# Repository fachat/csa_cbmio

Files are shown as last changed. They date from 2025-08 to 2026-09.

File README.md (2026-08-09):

# CBM-IO

Note: this is a part of a larger set of repositories, with [upet_family](https://github.com/fachat/upet_family) as the main repository.

This is the IO board for a re-incarnation of the Commodore B-Series to be used together with the Ultra-CPU board.

It is build on a Eurocard board and has only parts that can still be obtained new in 2025. In fact it uses an FPGA to emulate all the I/O chips of the B-Series.
It uses the [CS/A bus interface](http://www.6502.org/users/andre/csa/index.html) to connect with the CPU board.

Note: this is a work in progress!

The board

## Features

## Contributions

### VIA 6522

The VIA6522 is coming from Rhialto's Mega65 code at https://github.com/Rhialto/MegaPET/blob/rhialto/CORE/PET2001_MiSTer/rtl/via6522.vhd
which in turns originates from Gideon Zweijtzer.

I had to adapt it to the single Phi2 clock input though.

In the meantime it has been mostly rewritten esp. in the timer and shift register parts, along the lines
of the chip dissection from http://forum.6502.org .

### UART 16550

The UART seems to be a common 16550 core, made for the Wishbone bus.
it is taken from the Microwatt project https://github.com/antonblanchard/microwatt
and seems to originate from http://www.opencores.org/cores/uart16550/ but that page is not found anymore.

I again had to adapt it to the 6502 bus interface.

## Thanks

Many thanks go to Frank "androSID" Wolf and Dieter "ttlworks" Müller from the
[6502.org forum](https://forum.6502.org), who dissected the PIA and VIA chips (and many more).
This is an outstanding work and absolutely helpful in understanding how the chips work internally.

The relevant chip dissections are

- [VIA dissection](https://6502.org/forum/viewtopic.php?f=4&t=7241)
- [PIA dissection](https://6502.org/forum/viewtopic.php?f=4&t=7425)

For your interest, the full list of chip dissection is here [here on the forum](https://6502.org/forum/viewtopic.php?t=7427)

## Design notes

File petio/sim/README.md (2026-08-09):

# PETIO IC simulation scripts (GHDL)

This folder provides cycle-driven GHDL testbenches for:

- `via6522`
- `pia6520`
- `uart_shell`
- `Shell` (with a cycle-exact 6502 CPU model)

## Script format

Each line defines one cycle action (used by the via/pia/uart testbenches):

```text
<cycle> <op> [addr] [data]
```

- `cycle`: non-negative integer, strictly increasing
- `op`:
  - `W` write register (`addr` + `data` required)
  - `R` read register (`addr` required)
  - `N` no bus operation (pause)
- `addr`: register index in decimal
- `data`: byte value (0..255) in decimal

Blank lines and lines starting with `#` are ignored.

Pauses can be modeled in two ways:
- by using explicit `N` lines
- by leaving gaps between cycle numbers

## Run

From `/home/runner/work/csa_cbmio/csa_cbmio/petio/sim`:

- `make via`
- `make pia`
- `make uart`
- `make shell_cpu ROM=path/to/rom.bin`

Override script file:

- `make via SCRIPT=scripts/my_via.txt`

## Shell CPU testbench (`tb_shell_cpu`)

`tb_shell_cpu.vhd` instantiates the full `Shell.vhd` design and drives it with
the extracted `cpu6502.vhd` cycle-accurate behavioural 6502 CPU model.

### Memory map

| Address range | Description |
|---|---|
| `$0000–$03FF` | 1 kB RAM |
| `$E800–$E87F` | Shell I/O (`niosel` asserted) |
| `$E000–$FFFF` | 8 kB ROM loaded from `rom_file` (except `$E800–$E87F`, where Shell I/O has priority) |

### ROM loading

The ROM binary is specified via the `rom_file` generic (default: `rom.bin`).
If the binary is smaller than 8 kB it is placed at the **end** of the ROM
region so that the 6502 vector area (`$FFFA–$FFFF`) is always populated.

### Simulation flow

1. `nres` is held low for 8 clock cycles (reset).
2. `nres` is released; the CPU fetches the reset vector from `$FFFC/$FFFD`
   and begins executing ROM code.
3. Simulation ends when the CPU executes a `BRK` instruction (`$00`) or
   after 1 000 000 bus cycles (safety timeout).

### Running

```sh
make shell_cpu ROM=mytest.bin
```

The waveform is written to `shell_cpu.vcd`.

### Test fixture — exposed pin connections

To allow ROM test programs to exercise the I/O ports end-to-end, the
testbench cross-wires certain exposed pins so that writing to one pin and
reading back the opposite pin of the pair exercises the full output→wire→input
path. `std_logic` resolution is used throughout: whichever endpoint is
configured as an output drives the shared node with `'0'` or `'1'`; the
opposite end (configured as an input) drives the node with `'Z'`, which the
resolver ignores.

| Connection | Shell signal A | Shell signal B | Notes |
|---|---|---|---|
| VIA1 PA0 ↔ VIA1 PA1 | `up(0)` | `up(1)` | bidirectional |
| VIA1 PA2 ↔ VIA1 PA3 | `up(2)` | `up(3)` | bidirectional |
| VIA1 PA4 ↔ VIA1 PB3 | `up(7)` | `cwr` | bidirectional |
| VIA1 PA5 ↔ VIA1 PA6 | `up(6)` | `up(5)` | bidirectional |
| PIA1 PA7 ↔ VIA1 CB1 | `up(10)` | `up(12)` | bidirectional |
| PIA1 CA1 ↔ VIA1 CA2 | `c1rd` | `up(11)` | VIA1 CA2 → PIA1 CA1 only; PIA CA1 is always an input; `'1'` (idle) when CA2 is in input mode |

The pin mapping within `Shell.vhd` that translates internal VIA/PIA signals
to the Shell's external ports:

| VIA1/PIA1 pin | Shell external port bit |
|---|---|
| VIA1 PA0 | `up(0)` |
| VIA1 PA1 | `up(1)` |
| VIA1 PA2 | `up(2)` |
| VIA1 PA3 | `up(3)` |
| VIA1 PA4 | `up(7)` |
| VIA1 PA5 | `up(6)` |
| VIA1 PA6 | `up(5)` |
| VIA1 PB3 | `cwr` |
| VIA1 CA2 | `up(11)` |
| VIA1 CB1 | `up(12)` |
| PIA1 PA7 | `up(10)` |
| PIA1 CA1 | `c1rd` |

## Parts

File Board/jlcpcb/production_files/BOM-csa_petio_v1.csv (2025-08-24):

Comment | Designator | Footprint | LCSC | Quantity
4k7 | RN6 | R_Array_SIP5 | C11392 | 1
74LVC1G125 | U21,U22 | SOT-353_SC-70-5 | C12519 | 2
47u | C8 | C_0805_2012Metric_Pad1.18x1.45mm_HandSolder | C16780 | 1
Extended_PET_keyboard_connector | J14 | PET_Extended_Keyboard_Connector | C18202145 | 1
M09HPS | X3 | DSUB-9_Pins_Horizontal_P2.77x2.84mm_EdgePinOffset9.90mm_Housed_MountingHolesOffset11.32mm | C19077344 | 1
1k | R10,R3,R9 | R_0603_1608Metric_Pad0.98x0.95mm_HandSolder | C21190 | 3
10 | R6 | 0207_10 | C2149605 | 1
74LVC1G04 | U14 | SOT-23-5 | C22356929 | 1
330 | R2,R4,R7,R8 | R_0603_1608Metric_Pad0.98x0.95mm_HandSolder | C23138 | 4
4k7 | R1,R5 | R_0603_1608Metric_Pad0.98x0.95mm_HandSolder | C23162 | 2
SN75161BDW | U5 | SOIC-20W_7.5x12.8mm_P1.27mm | C2671348 | 1
LSF0204Q | U16,U17,U18,U19,U6,U7,U8,U9 | TSSOP-14_4.4x5mm_P0.65mm | C2677502 | 8
XC6SLX9-TQG144 | U1 | TQFP-144_20x20mm_P0.5mm | C27408 | 1
74LVC8T245SO24 | IC16 | TSSOP-24_6.1x7.8mm_P0.65mm | C27643 | 1
100n | C1,C10,C15,C16,C17,C18,C19,C2,C20,C21,C22,C23,C24,C25,C26,C27,C28,C29,C3,C30,C31,C32,C33,C34,C35,C36,C37,C38,C39,C40,C9 | C_0805_2012Metric | C28233 | 31
1u | C11,C12,C13,C14 | C_0805_2012Metric_Pad1.18x1.45mm_HandSolder | C28323 | 4
AP2132BB | UX16 | Diodes_PSOP-8 | C338874 | 1
22u | C4,C5,C6,C7 | C_0805_2012Metric_Pad1.18x1.45mm_HandSolder | C45783 | 4
JP1E | JP1,JP18,JP22 | JP1 | C492401 | 3
CBMTAPE | P5 | JP6 | C492405 | 1
Conn_01x09 | J11,J12 | PinHeader_1x09_P2.54mm_Vertical | C492408 | 2
4051 | U12,U13 | SOP-16_3.9x9.9mm_P1.27mm | C507163 | 2
74LS06 | U10 | SO-14_3.9x8.65mm_P1.27mm | C513512 | 1
PETUSERPORT | P1,P2 | FLAT24_IDC | C5157635 | 2
CSABUS | P4 | CSABUS | C5173362 | 1
~ | P9,UX7 | IDC-Header_2x05_P2.54mm_Vertical | C5665 | 2
LDI1117 | UX17 | SOT-223 | C6186 | 1
ADM560 | U15 | SSOP-28_5.3x10.2mm_P0.65mm | C658278 | 1
SPIFLASH | UX18 | DIP-8_W7.62mm_Socket_LongPads | C72124 | 1
Conn_01x23 | J2 | PinSocket_1x23_P2.54mm_Vertical | C725955 | 1
~ | U20 | IDC-Header_2x13_P2.54mm_Vertical | C7501247 | 1
SN74LVC245APW | U11,U2,U3 | TSSOP-20_4.4x6.5mm_P0.65mm | C7848 | 3
74LVC1G00 | U23 | SOT-353_SC-70-5_Handsoldering | C8185 | 1
10k | RN1,RN2,RN3,RN4,RN5 | R_Array_SIP9 | C8692 | 5
SN75160BDW | U4 | SOIC-20W_7.5x12.8mm_P1.27mm | C882412 | 1
DIN-6 | J1 | DIN6PIEC |  | 1
PIEZOBEEPERPIEZO | BEEP1 | PIEZOBEEPER |  | 1

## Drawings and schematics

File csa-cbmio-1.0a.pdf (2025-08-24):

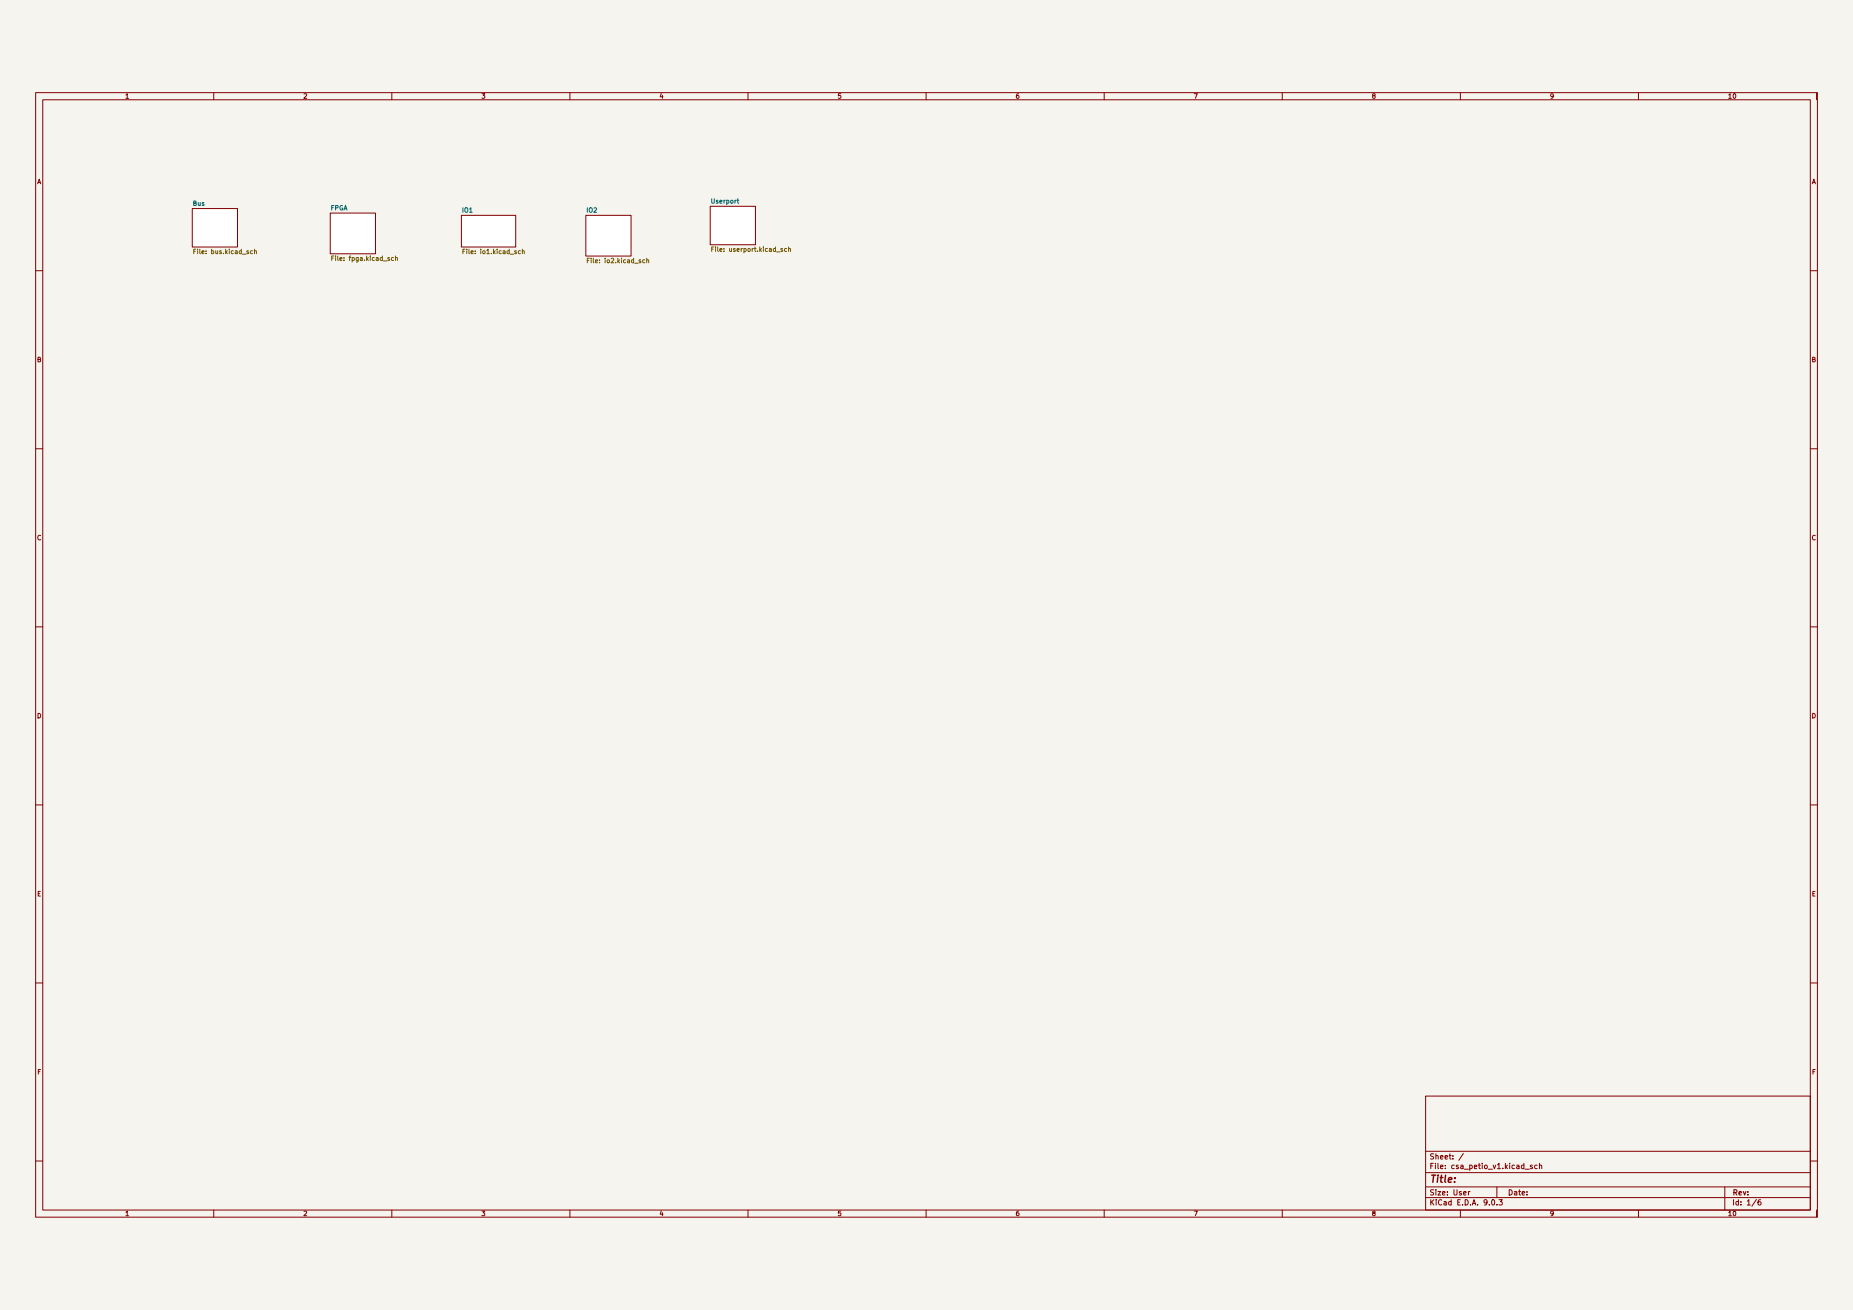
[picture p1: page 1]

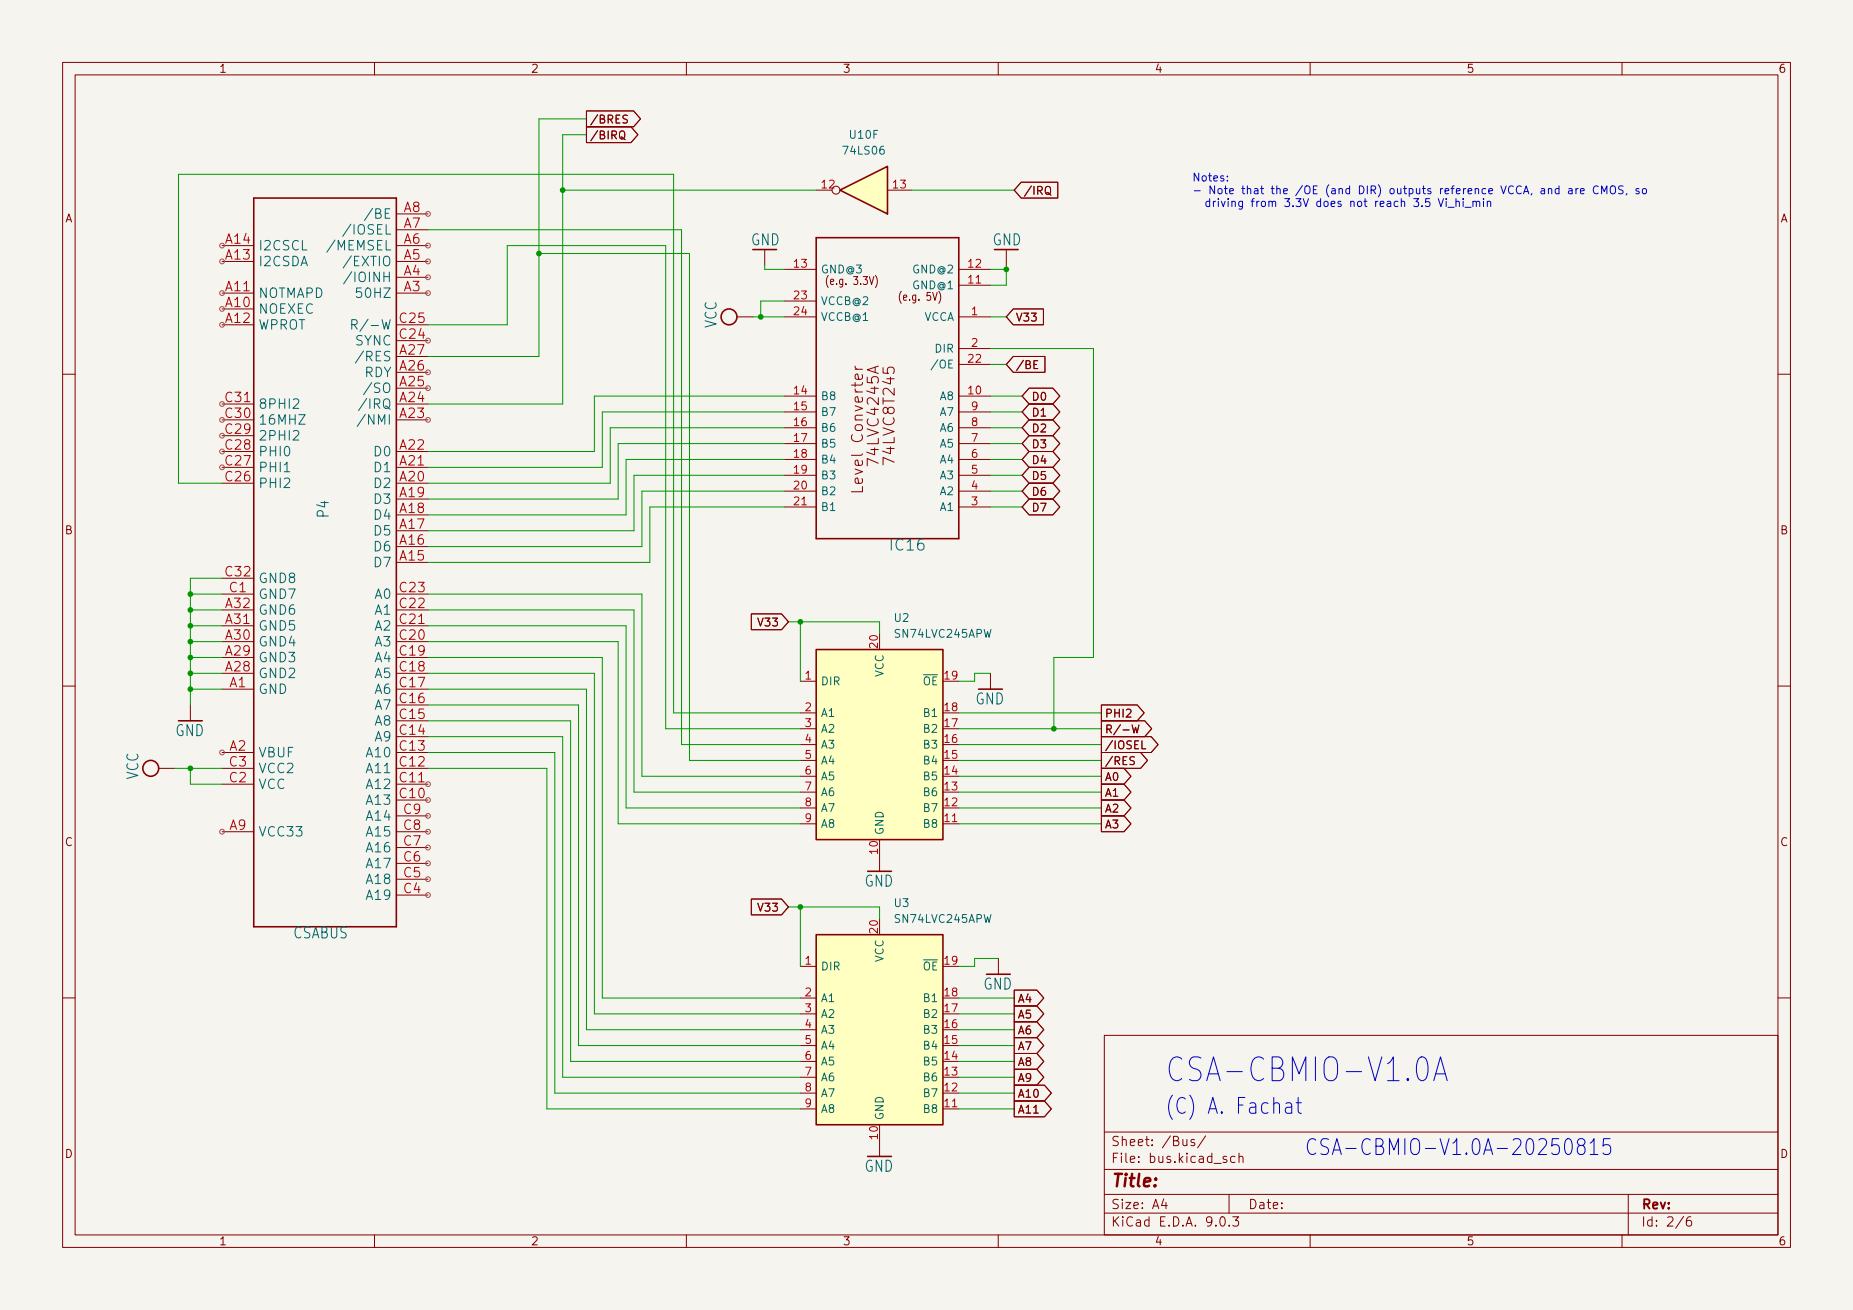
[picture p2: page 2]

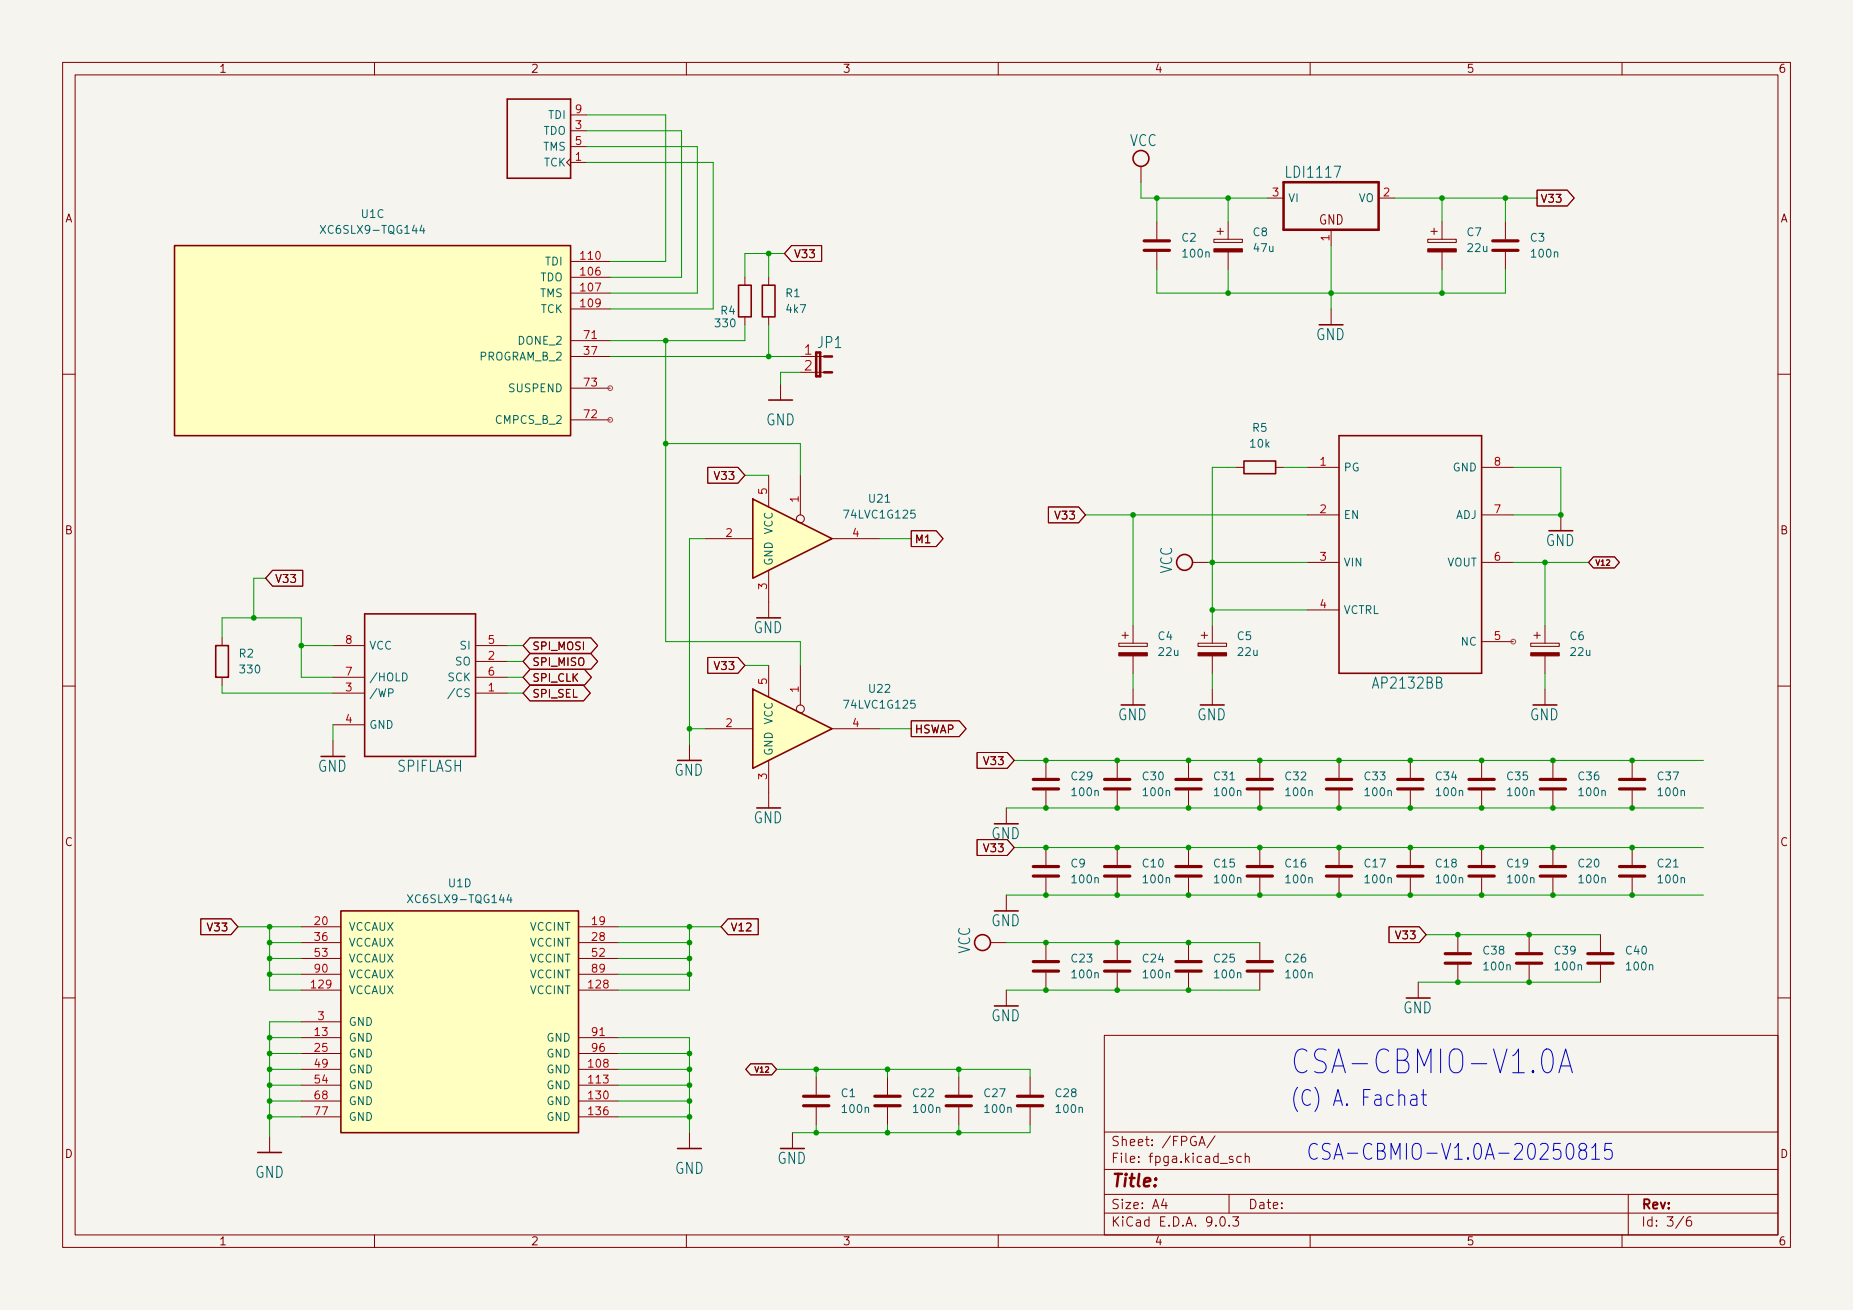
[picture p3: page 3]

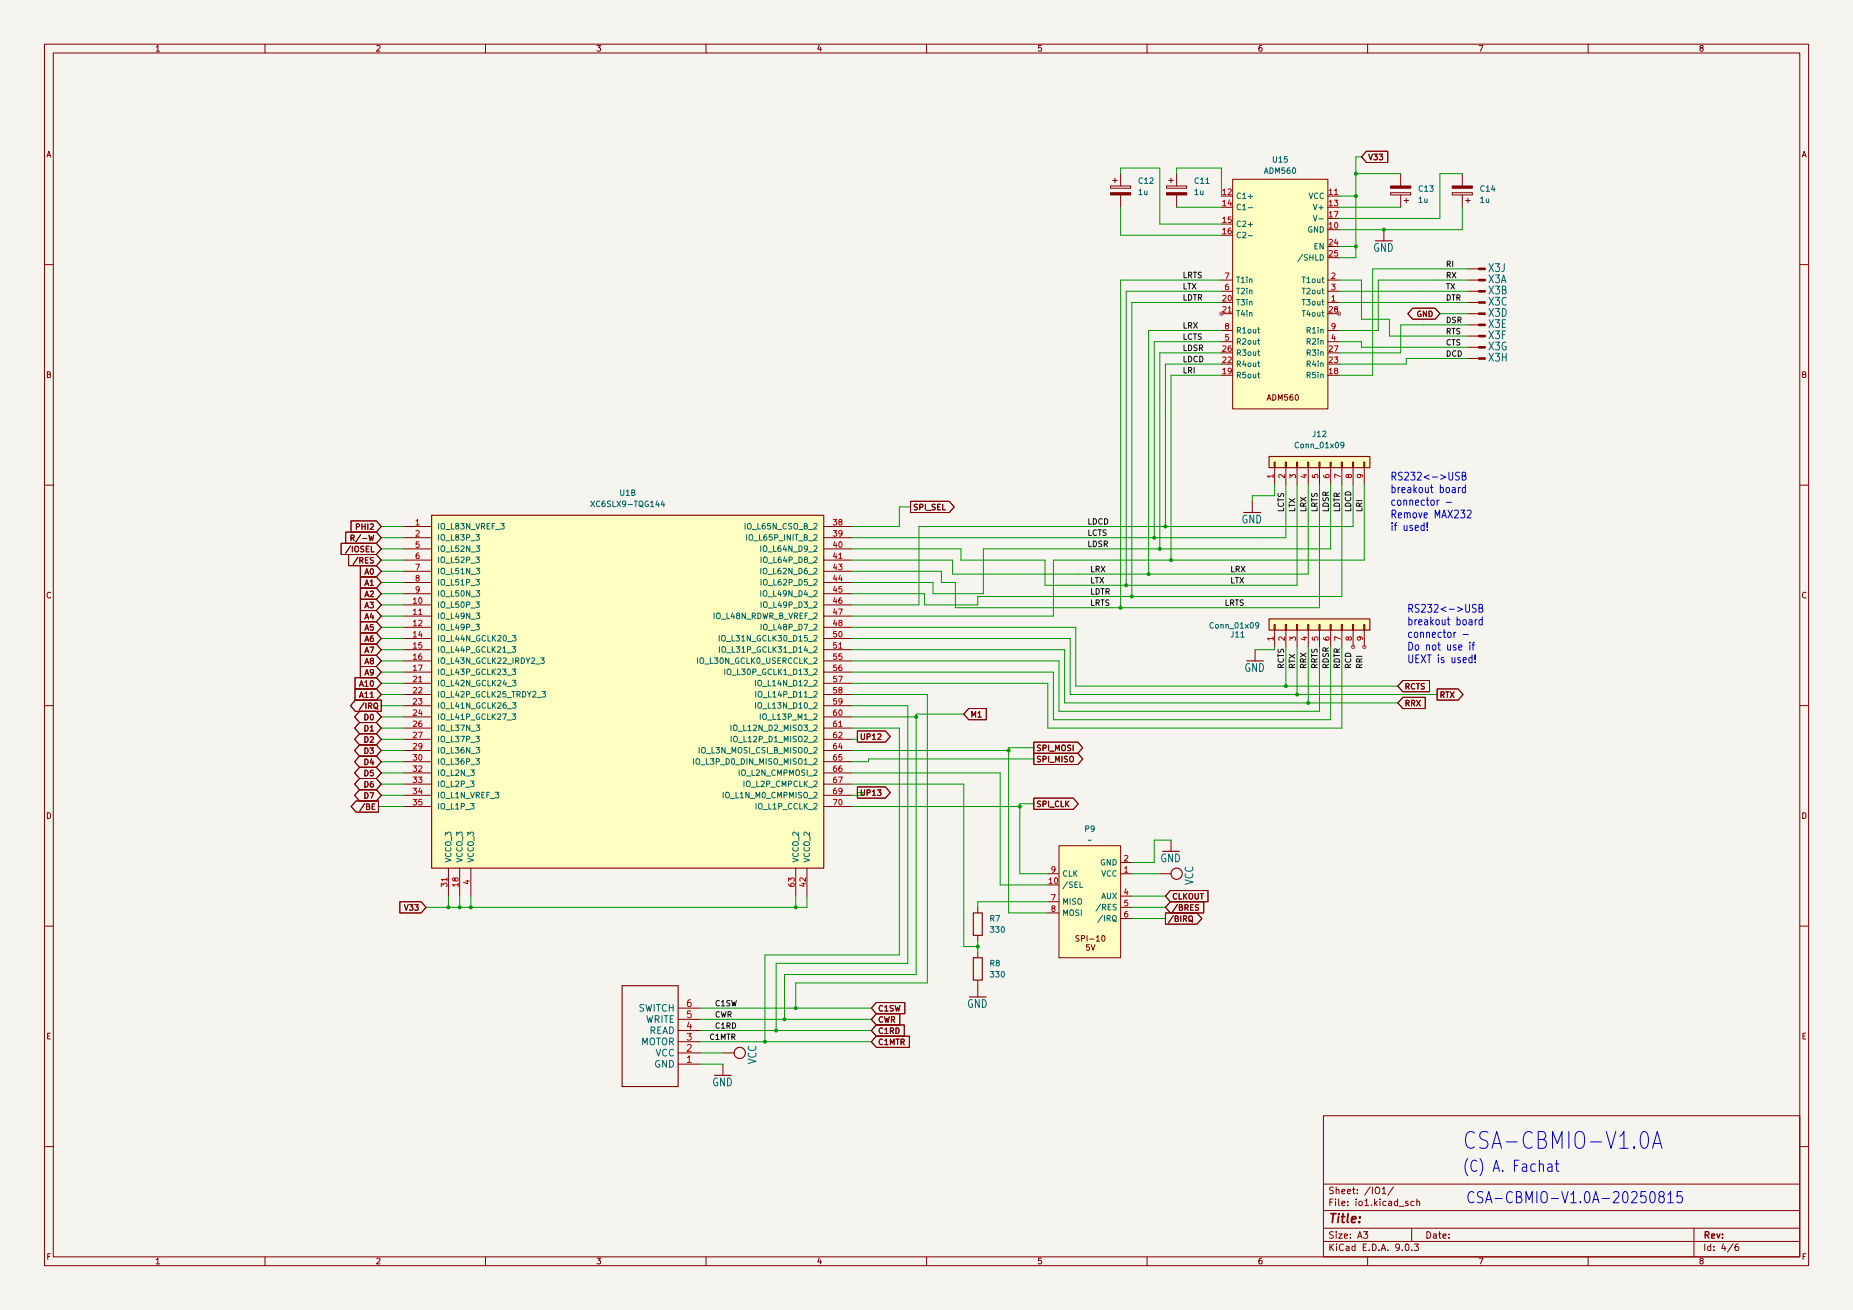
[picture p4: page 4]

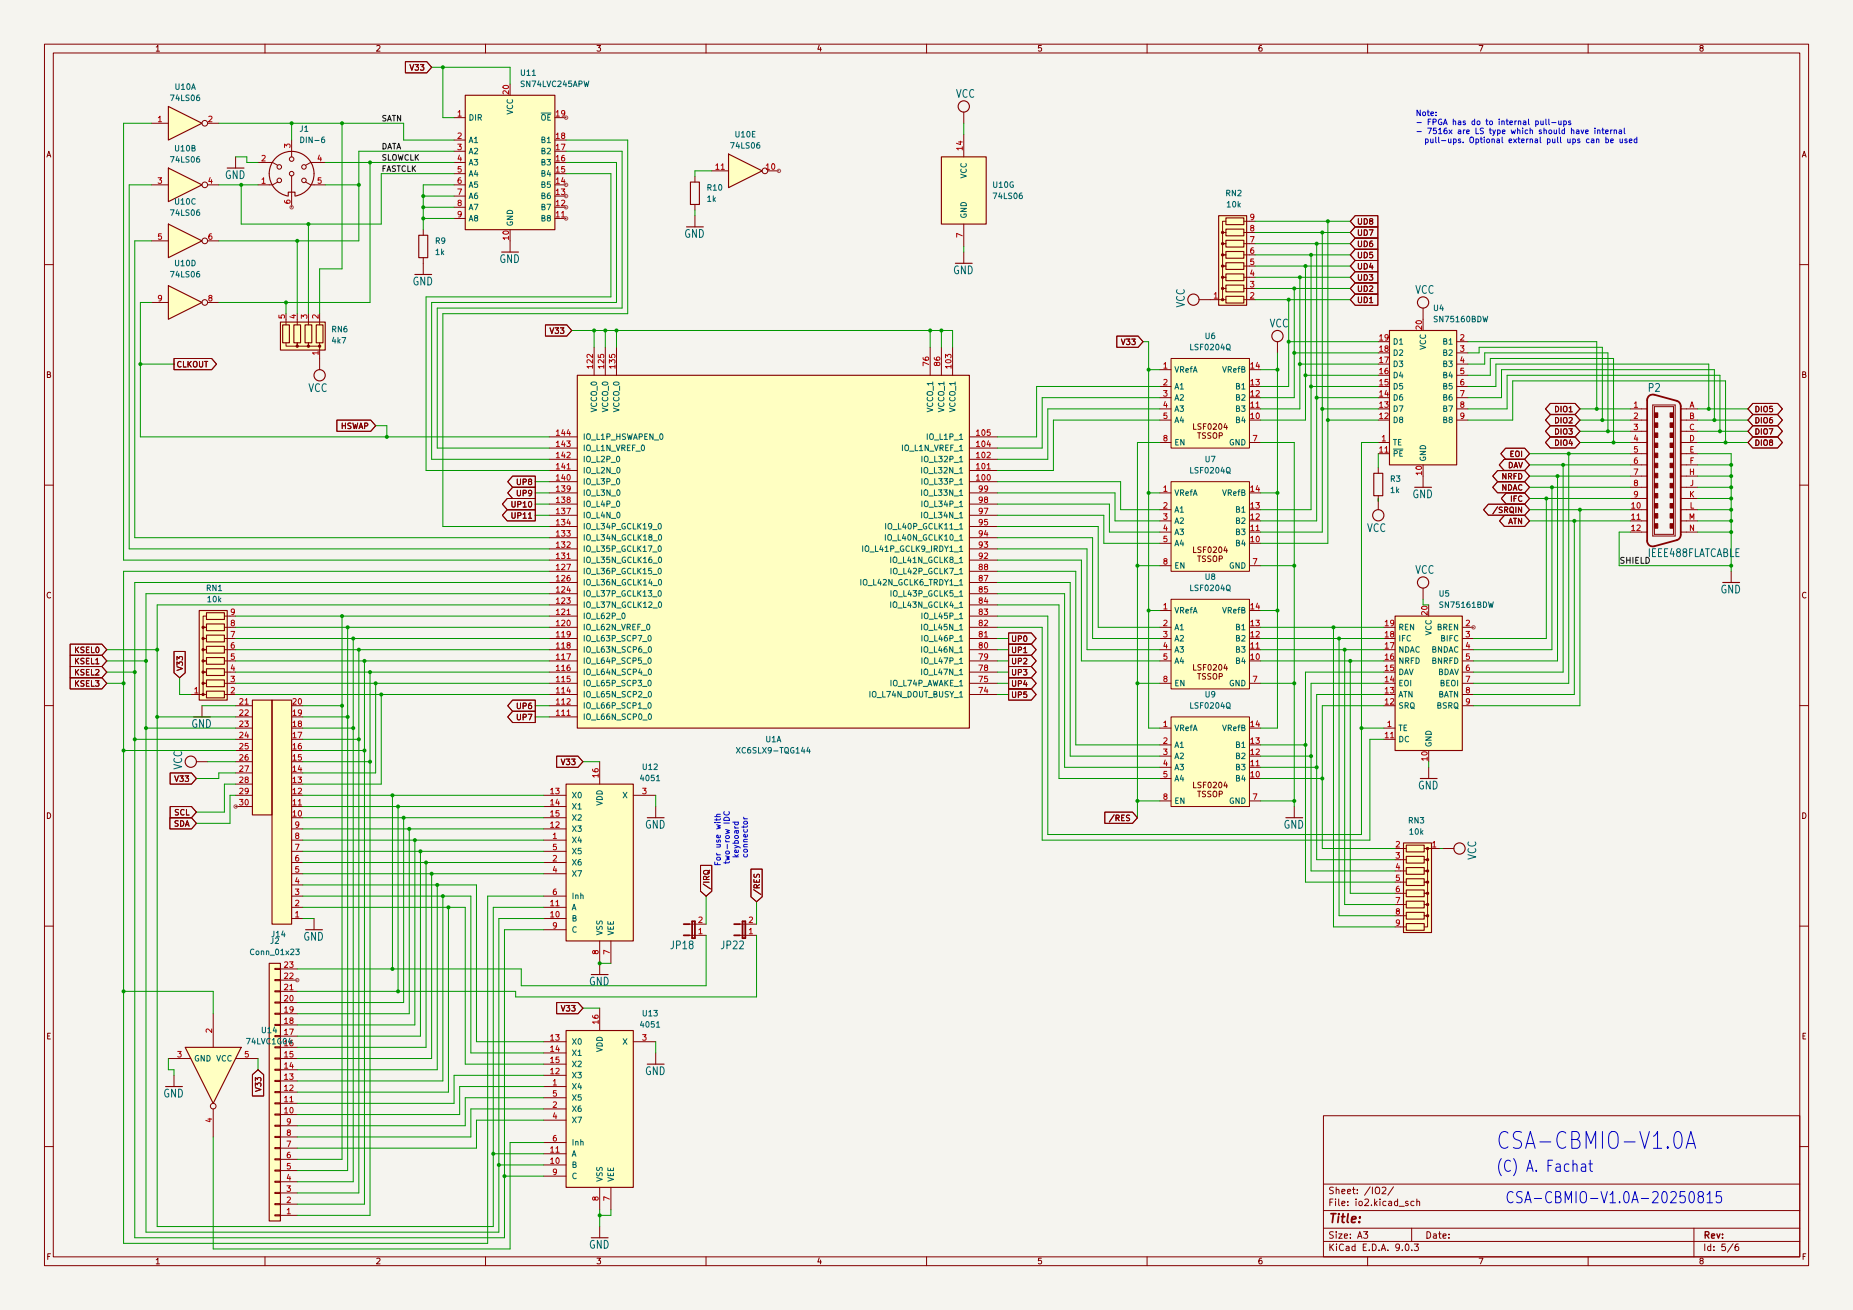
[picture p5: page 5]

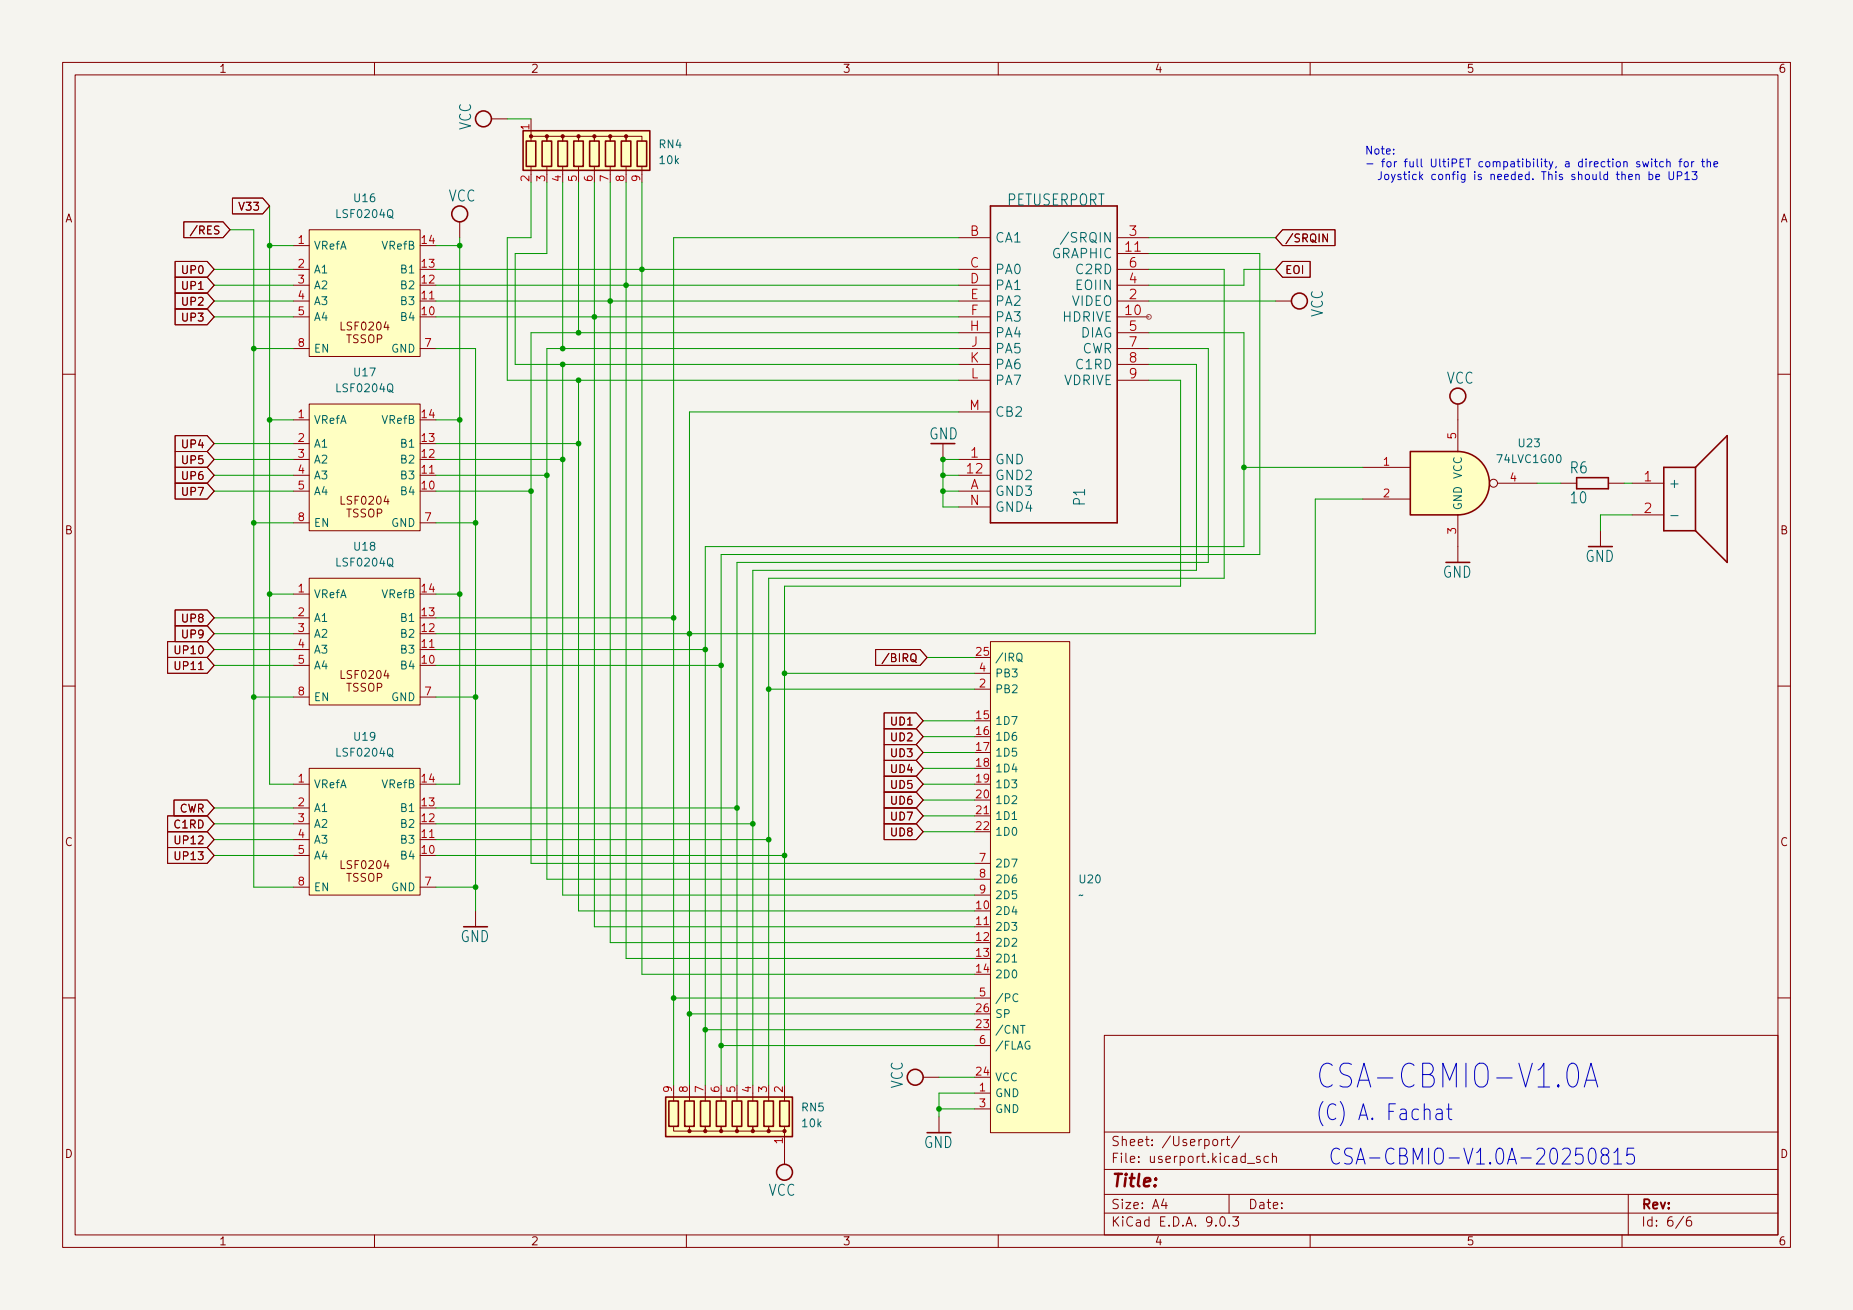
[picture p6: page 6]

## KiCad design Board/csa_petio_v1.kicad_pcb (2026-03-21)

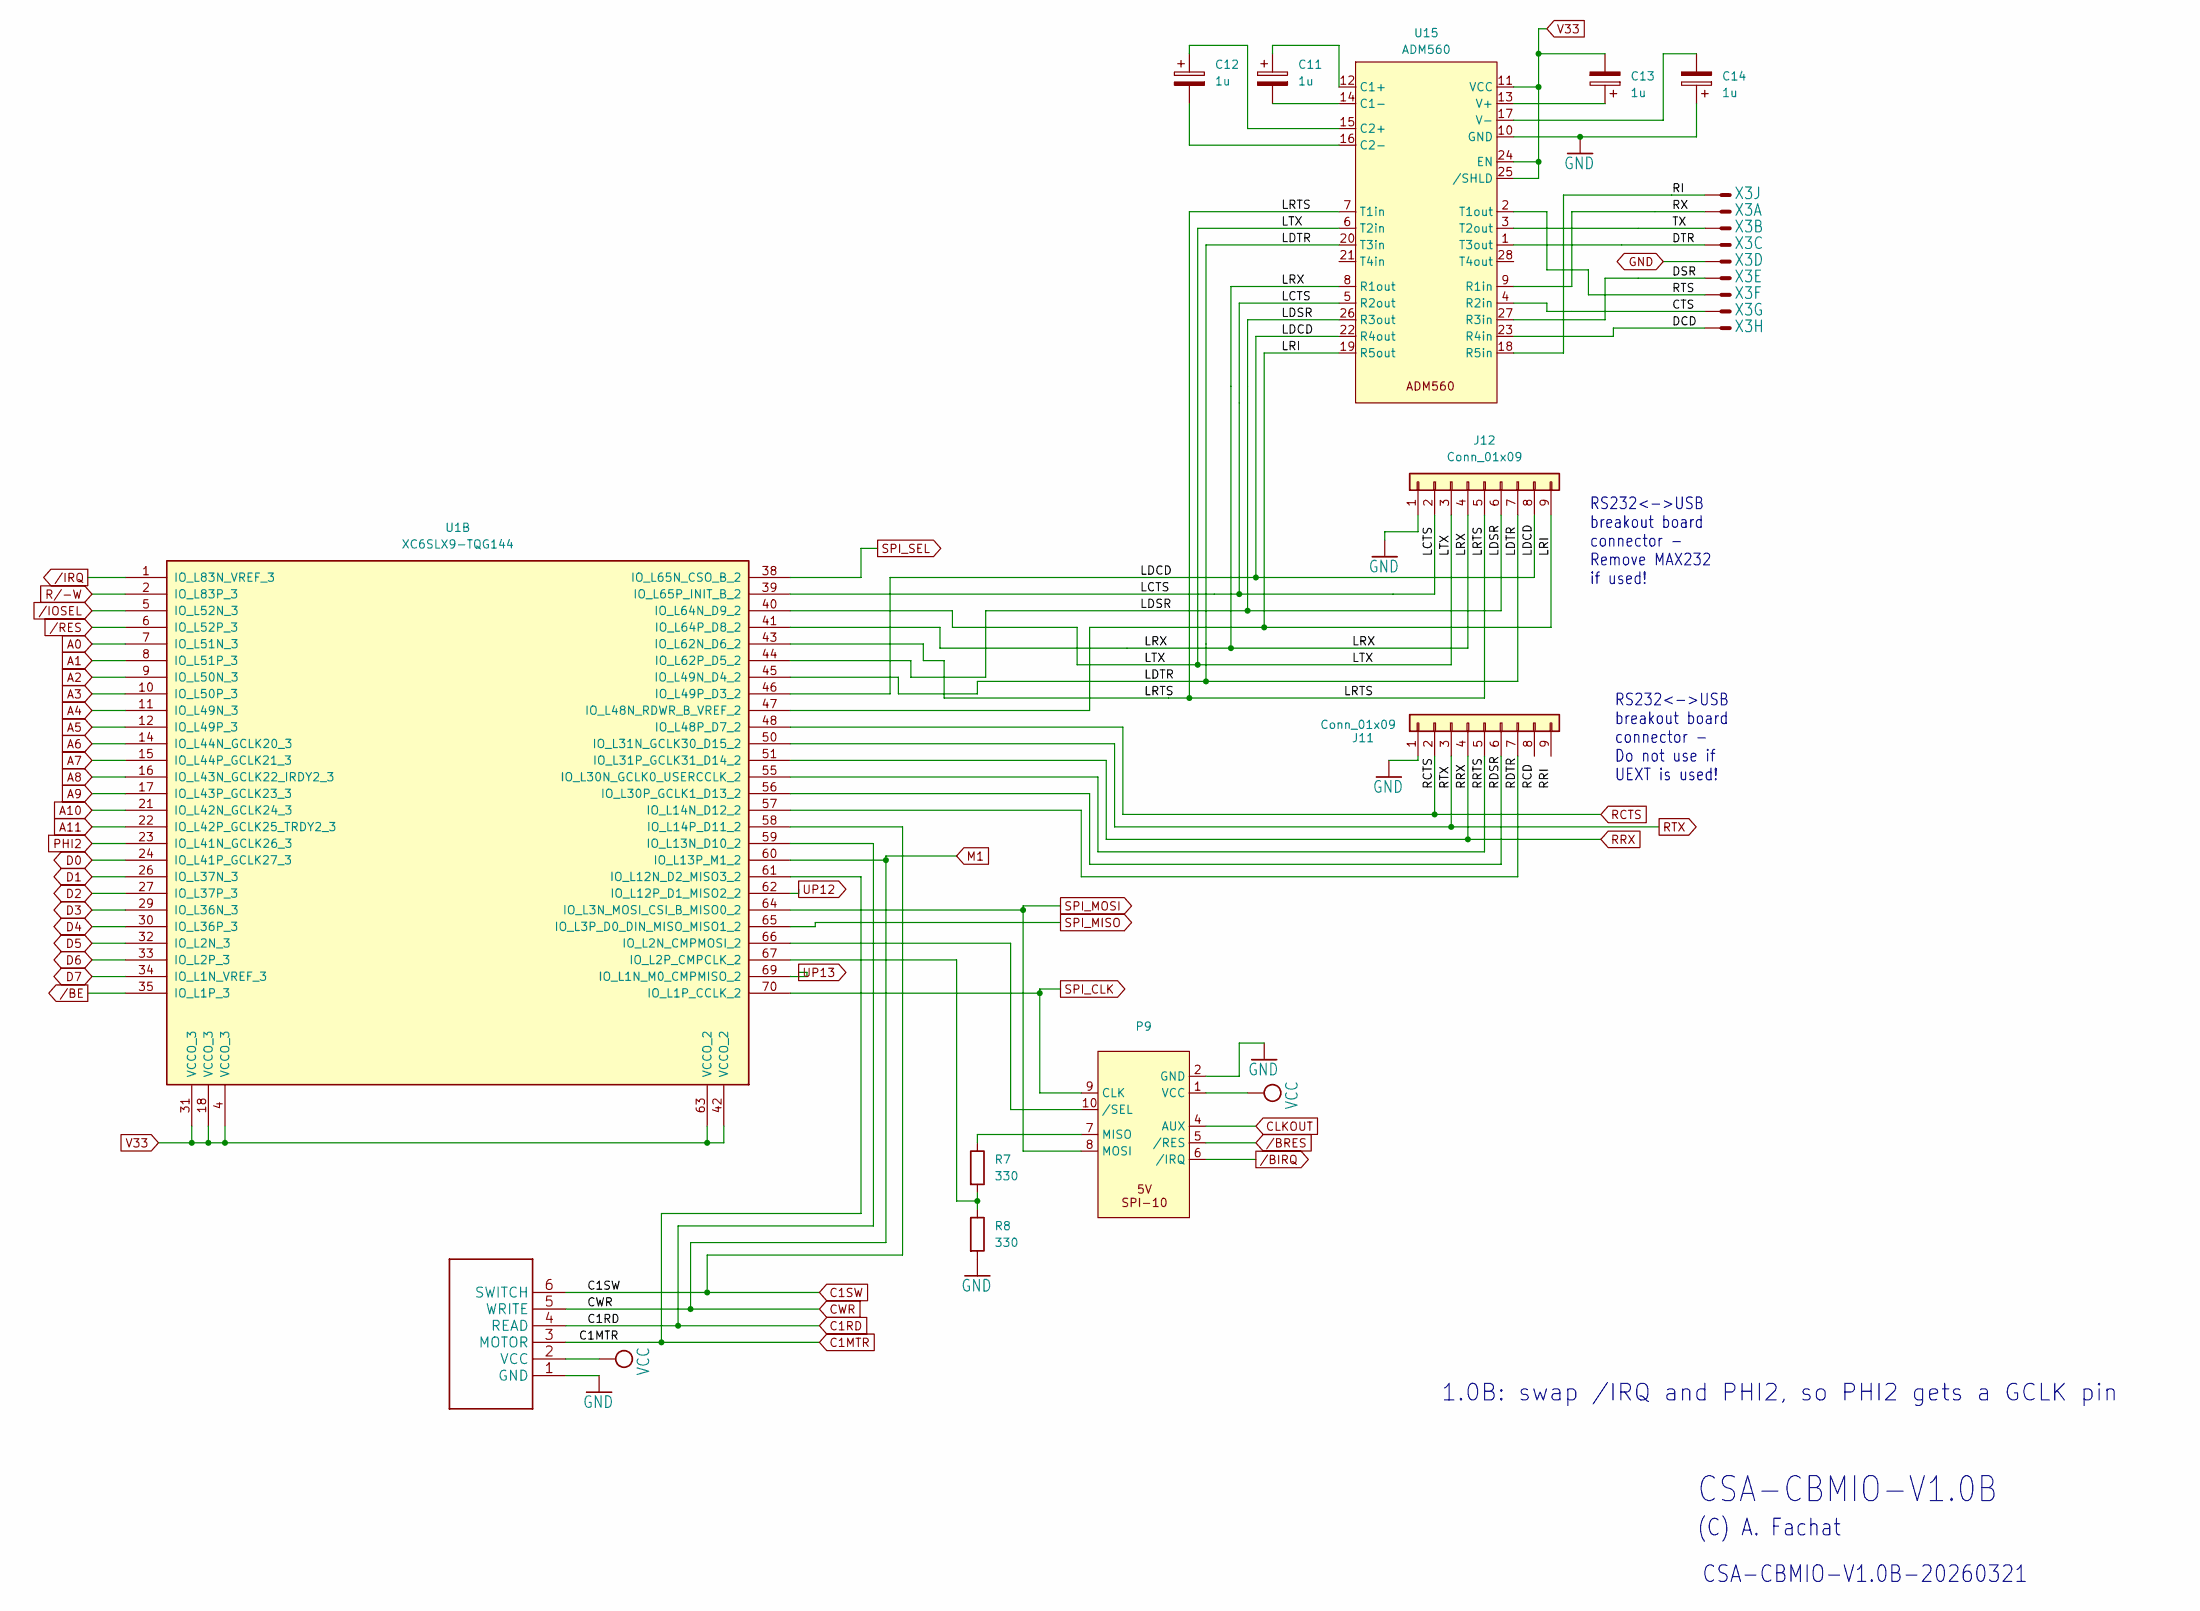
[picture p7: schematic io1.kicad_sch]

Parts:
C11, C12, C13, C14: 1u; C_0805_2012Metric_Pad1.18x1.45mm_HandSolder
J11, J12: Conn_01x09; PinHeader_1x09_P2.54mm_Vertical
P5: CBMTAPE; JP6
P9: IDC-Header_2x05_P2.54mm_Vertical
R7, R8: 330; R_0603_1608Metric_Pad0.98x0.95mm_HandSolder
U1: XC6SLX9-TQG144; TQFP-144_20x20mm_P0.5mm
U15: ADM560; SSOP-28_5.3x10.2mm_P0.65mm
X3: M09HPS; DSUB-9_Pins_Horizontal_P2.77x2.84mm_EdgePinOffset9.90mm_Hou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

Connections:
/IO1/CTS: U15.4 (R2in), X3.8 (M)
/IO1/DCD: U15.23 (R4in), X3.9 (M)
/IO1/DSR: U15.27 (R3in), X3.6 (M)
/IO1/DTR: U15.1 (T3out), X3.4 (M)
/IO1/LCTS: J12.2, U1.39 (IO_L65P_INIT_B_2), U15.5 (R2out)
/IO1/LDCD: J12.8, U1.46 (IO_L49P_D3_2), U15.22 (R4out)
/IO1/LDSR: J12.6, U1.44 (IO_L62P_D5_2), U15.26 (R3out)
/IO1/LDTR: J12.7, U1.45 (IO_L49N_D4_2), U15.20 (T3in)
/IO1/LRI: J12.9, U1.47 (IO_L48N_RDWR_B_VREF_2), U15.19 (R5out)
/IO1/LRTS: J12.5, U1.43 (IO_L62N_D6_2), U15.7 (T1in)
/IO1/LRX: J12.4, U1.41 (IO_L64P_D8_2), U15.8 (R1out)
/IO1/LTX: J12.3, U1.40 (IO_L64N_D9_2), U15.6 (T2in)
/IO1/RDSR: J11.6, U1.56 (IO_L30P_GCLK1_D13_2)
/IO1/RDTR: J11.7, U1.57 (IO_L14N_D12_2)
/IO1/RI: U15.18 (R5in), X3.1 (M)
/IO1/RRTS: J11.5, U1.55 (IO_L30N_GCLK0_USERCCLK_2)
/IO1/RTS: U15.2 (T1out), X3.7 (M)
/IO1/RX: U15.9 (R1in), X3.2 (M)
/IO1/TX: U15.3 (T2out), X3.3 (M)
A0: U1.7 (IO_L51N_3); also elsewhere on the board
A1: U1.8 (IO_L51P_3); also elsewhere on the board
A2: U1.9 (IO_L50N_3); also elsewhere on the board
A3: U1.10 (IO_L50P_3); also elsewhere on the board
A4: U1.11 (IO_L49N_3); also elsewhere on the board
A5: U1.12 (IO_L49P_3); also elsewhere on the board
A6: U1.14 (IO_L44N_GCLK20_3); also elsewhere on the board
A7: U1.15 (IO_L44P_GCLK21_3); also elsewhere on the board
A8: U1.16 (IO_L43N_GCLK22_IRDY2_3); also elsewhere on the board
A9: U1.17 (IO_L43P_GCLK23_3); also elsewhere on the board
A10: U1.21 (IO_L42N_GCLK24_3); also elsewhere on the board
A11: U1.22 (IO_L42P_GCLK25_TRDY2_3); also elsewhere on the board
C1MTR: P5.3 (MOTOR), U1.61 (IO_L12N_D2_MISO3_2)
C1RD: P5.4 (READ), U1.59 (IO_L13N_D10_2); also elsewhere on the board
C1SW: P5.6 (SWITCH), U1.58 (IO_L14P_D11_2)
CLKOUT: P9.4 (AUX); also elsewhere on the board
CWR: P5.5 (WRITE), U1.60 (IO_L13P_M1_2); also elsewhere on the board
D0: U1.24 (IO_L41P_GCLK27_3); also elsewhere on the board
D1: U1.26 (IO_L37N_3); also elsewhere on the board
D2: U1.27 (IO_L37P_3); also elsewhere on the board
D3: U1.29 (IO_L36N_3); also elsewhere on the board
D4: U1.30 (IO_L36P_3); also elsewhere on the board
D5: U1.32 (IO_L2N_3); also elsewhere on the board
D6: U1.33 (IO_L2P_3); also elsewhere on the board
D7: U1.34 (IO_L1N_VREF_3); also elsewhere on the board
GND: C14.1, J11.1, J12.1, P5.1 (GND), P9.2 (GND), R8.2, U15.10 (GND), X3.5 (M); also elsewhere on the board
unnamed: P9.7 (MISO), R7.1
unnamed: P9.10 (/SEL), U1.66 (IO_L2N_CMPMOSI_2)
unnamed: R7.2, R8.1, U1.67 (IO_L2P_CMPCLK_2)
unnamed: C11.1, U15.12 (C1+)
unnamed: C11.2, U15.14 (C1-)
unnamed: C12.1, U15.15 (C2+)
unnamed: C12.2, U15.16 (C2-)
unnamed: C13.1, U15.13 (V+)
unnamed: C14.2, U15.17 (V-)
PHI2: U1.23 (IO_L41N_GCLK26_3); also elsewhere on the board
RCTS: J11.2, U1.48 (IO_L48P_D7_2)
RRX: J11.4, U1.51 (IO_L31P_GCLK31_D14_2)
RTX: J11.3, U1.50 (IO_L31N_GCLK30_D15_2)
R/-W: U1.2 (IO_L83P_3); also elsewhere on the board
SPI_CLK: P9.9 (CLK), U1.70 (IO_L1P_CCLK_2); also elsewhere on the board
SPI_MISO: U1.65 (IO_L3P_D0_DIN_MISO_MISO1_2); also elsewhere on the board
SPI_MOSI: P9.8 (MOSI), U1.64 (IO_L3N_MOSI_CSI_B_MISO0_2); also elsewhere on the board
SPI_SEL: U1.38 (IO_L65N_CSO_B_2); also elsewhere on the board
UP12: U1.62 (IO_L12P_D1_MISO2_2); also elsewhere on the board
UP13: U1.69 (IO_L1N_M0_CMPMISO_2); also elsewhere on the board
V33: C13.2, U1.4 (VCCO_3), U1.18 (VCCO_3), U1.31 (VCCO_3), U1.42 (VCCO_2), U1.63 (VCCO_2), U15.11 (VCC), U15.24 (EN), U15.25 (/SHLD); also elsewhere on the board
VCC: P5.2 (VCC), P9.1 (VCC); also elsewhere on the board
/BE: U1.35 (IO_L1P_3); also elsewhere on the board
/BIRQ: P9.6 (/IRQ); also elsewhere on the board
/BRES: P9.5 (/RES); also elsewhere on the board
/IOSEL: U1.5 (IO_L52N_3); also elsewhere on the board
/IRQ: U1.1 (IO_L83N_VREF_3); also elsewhere on the board
/RES: U1.6 (IO_L52P_3); also elsewhere on the board

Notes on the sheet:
1.0B: swap /IRQ and PHI2, so PHI2 gets a GCLK pin
CSA-CBMIO-V1.0B-20260321
RS232<->USB breakout board connector - Do not use if UEXT is used!
RS232<->USB breakout board connector - Remove MAX232 if used!
(C) A. Fachat
CSA-CBMIO-V1.0B

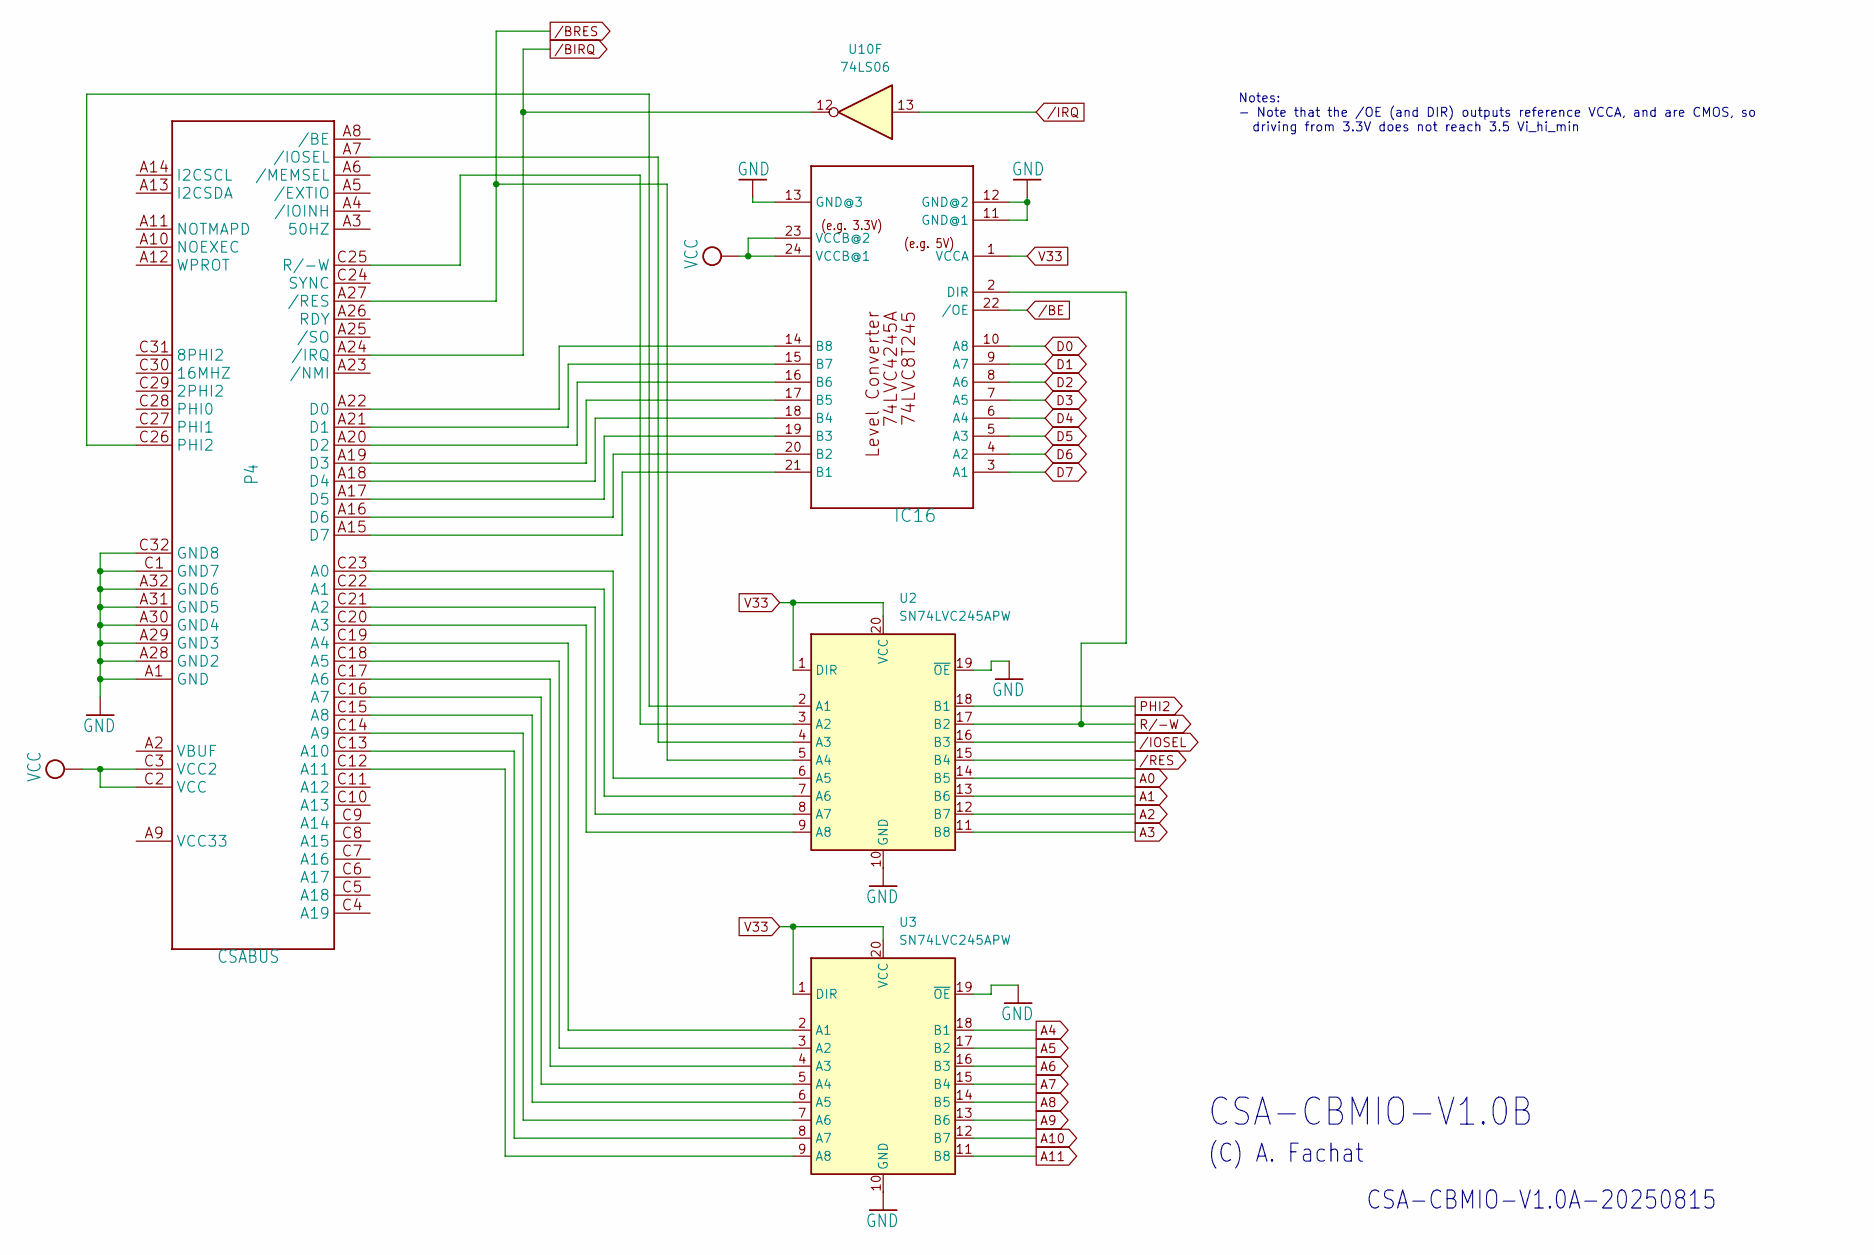
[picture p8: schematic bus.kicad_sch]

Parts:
IC16: 74LVC8T245SO24; TSSOP-24_6.1x7.8mm_P0.65mm
P4: CSABUS
U2, U3: SN74LVC245APW; TSSOP-20_4.4x6.5mm_P0.65mm
U10: 74LS06; SO-14_3.9x8.65mm_P1.27mm

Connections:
A0: U2.14 (B5); also elsewhere on the board
A1: U2.13 (B6); also elsewhere on the board
A2: U2.12 (B7); also elsewhere on the board
A3: U2.11 (B8); also elsewhere on the board
A4: U3.18 (B1); also elsewhere on the board
A5: U3.17 (B2); also elsewhere on the board
A6: U3.16 (B3); also elsewhere on the board
A7: U3.15 (B4); also elsewhere on the board
A8: U3.14 (B5); also elsewhere on the board
A9: U3.13 (B6); also elsewhere on the board
A10: U3.12 (B7); also elsewhere on the board
A11: U3.11 (B8); also elsewhere on the board
D0: IC16.10 (A8); also elsewhere on the board
D1: IC16.9 (A7); also elsewhere on the board
D2: IC16.8 (A6); also elsewhere on the board
D3: IC16.7 (A5); also elsewhere on the board
D4: IC16.6 (A4); also elsewhere on the board
D5: IC16.5 (A3); also elsewhere on the board
D6: IC16.4 (A2); also elsewhere on the board
D7: IC16.3 (A1); also elsewhere on the board
GND: IC16.11 (GND@1), IC16.12 (GND@2), IC16.13 (GND@3), P4.A1 (GND), P4.A28 (GND2), P4.A29 (GND3), P4.A30 (GND4), P4.A31 (GND5), P4.A32 (GND6), P4.C1 (GND7), P4.C32 (GND8), U2.10 (GND), U2.19 (~OE), U3.10 (GND), U3.19 (~OE); also elsewhere on the board
unnamed: IC16.21 (B1), P4.A15 (D7)
unnamed: IC16.20 (B2), P4.A16 (D6)
unnamed: IC16.19 (B3), P4.A17 (D5)
unnamed: IC16.18 (B4), P4.A18 (D4)
unnamed: IC16.17 (B5), P4.A19 (D3)
unnamed: IC16.16 (B6), P4.A20 (D2)
unnamed: IC16.15 (B7), P4.A21 (D1)
unnamed: IC16.14 (B8), P4.A22 (D0)
unnamed: P4.C23 (A0), U2.6 (A5)
unnamed: P4.C22 (A1), U2.7 (A6)
unnamed: P4.C21 (A2), U2.8 (A7)
unnamed: P4.C20 (A3), U2.9 (A8)
unnamed: P4.C19 (A4), U3.2 (A1)
unnamed: P4.C18 (A5), U3.3 (A2)
unnamed: P4.C17 (A6), U3.4 (A3)
unnamed: P4.C16 (A7), U3.5 (A4)
unnamed: P4.C15 (A8), U3.6 (A5)
unnamed: P4.C14 (A9), U3.7 (A6)
unnamed: P4.C13 (A10), U3.8 (A7)
unnamed: P4.C12 (A11), U3.9 (A8)
unnamed: P4.C26 (PHI2), U2.2 (A1)
unnamed: P4.C25 (R/-W), U2.3 (A2)
unnamed: P4.A7 (/IOSEL), U2.4 (A3)
PHI2: U2.18 (B1); also elsewhere on the board
R/-W: IC16.2 (DIR), U2.17 (B2); also elsewhere on the board
V33: IC16.1 (VCCA), U2.1 (DIR), U2.20 (VCC), U3.1 (DIR), U3.20 (VCC); also elsewhere on the board
VCC: IC16.23 (VCCB@2), IC16.24 (VCCB@1), P4.C2 (VCC), P4.C3 (VCC2); also elsewhere on the board
/BE: IC16.22 (/OE); also elsewhere on the board
/BIRQ: P4.A24 (/IRQ), U10.12; also elsewhere on the board
/BRES: P4.A27 (/RES), U2.5 (A4); also elsewhere on the board
/IOSEL: U2.16 (B3); also elsewhere on the board
/IRQ: U10.13; also elsewhere on the board
/RES: U2.15 (B4); also elsewhere on the board

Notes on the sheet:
Notes: - Note that the /OE (and DIR) outputs reference VCCA, and are CMOS, so driving from 3.3V does not reach 3.5 Vi_hi_min
CSA-CBMIO-V1.0B
(C) A. Fachat
CSA-CBMIO-V1.0A-20250815

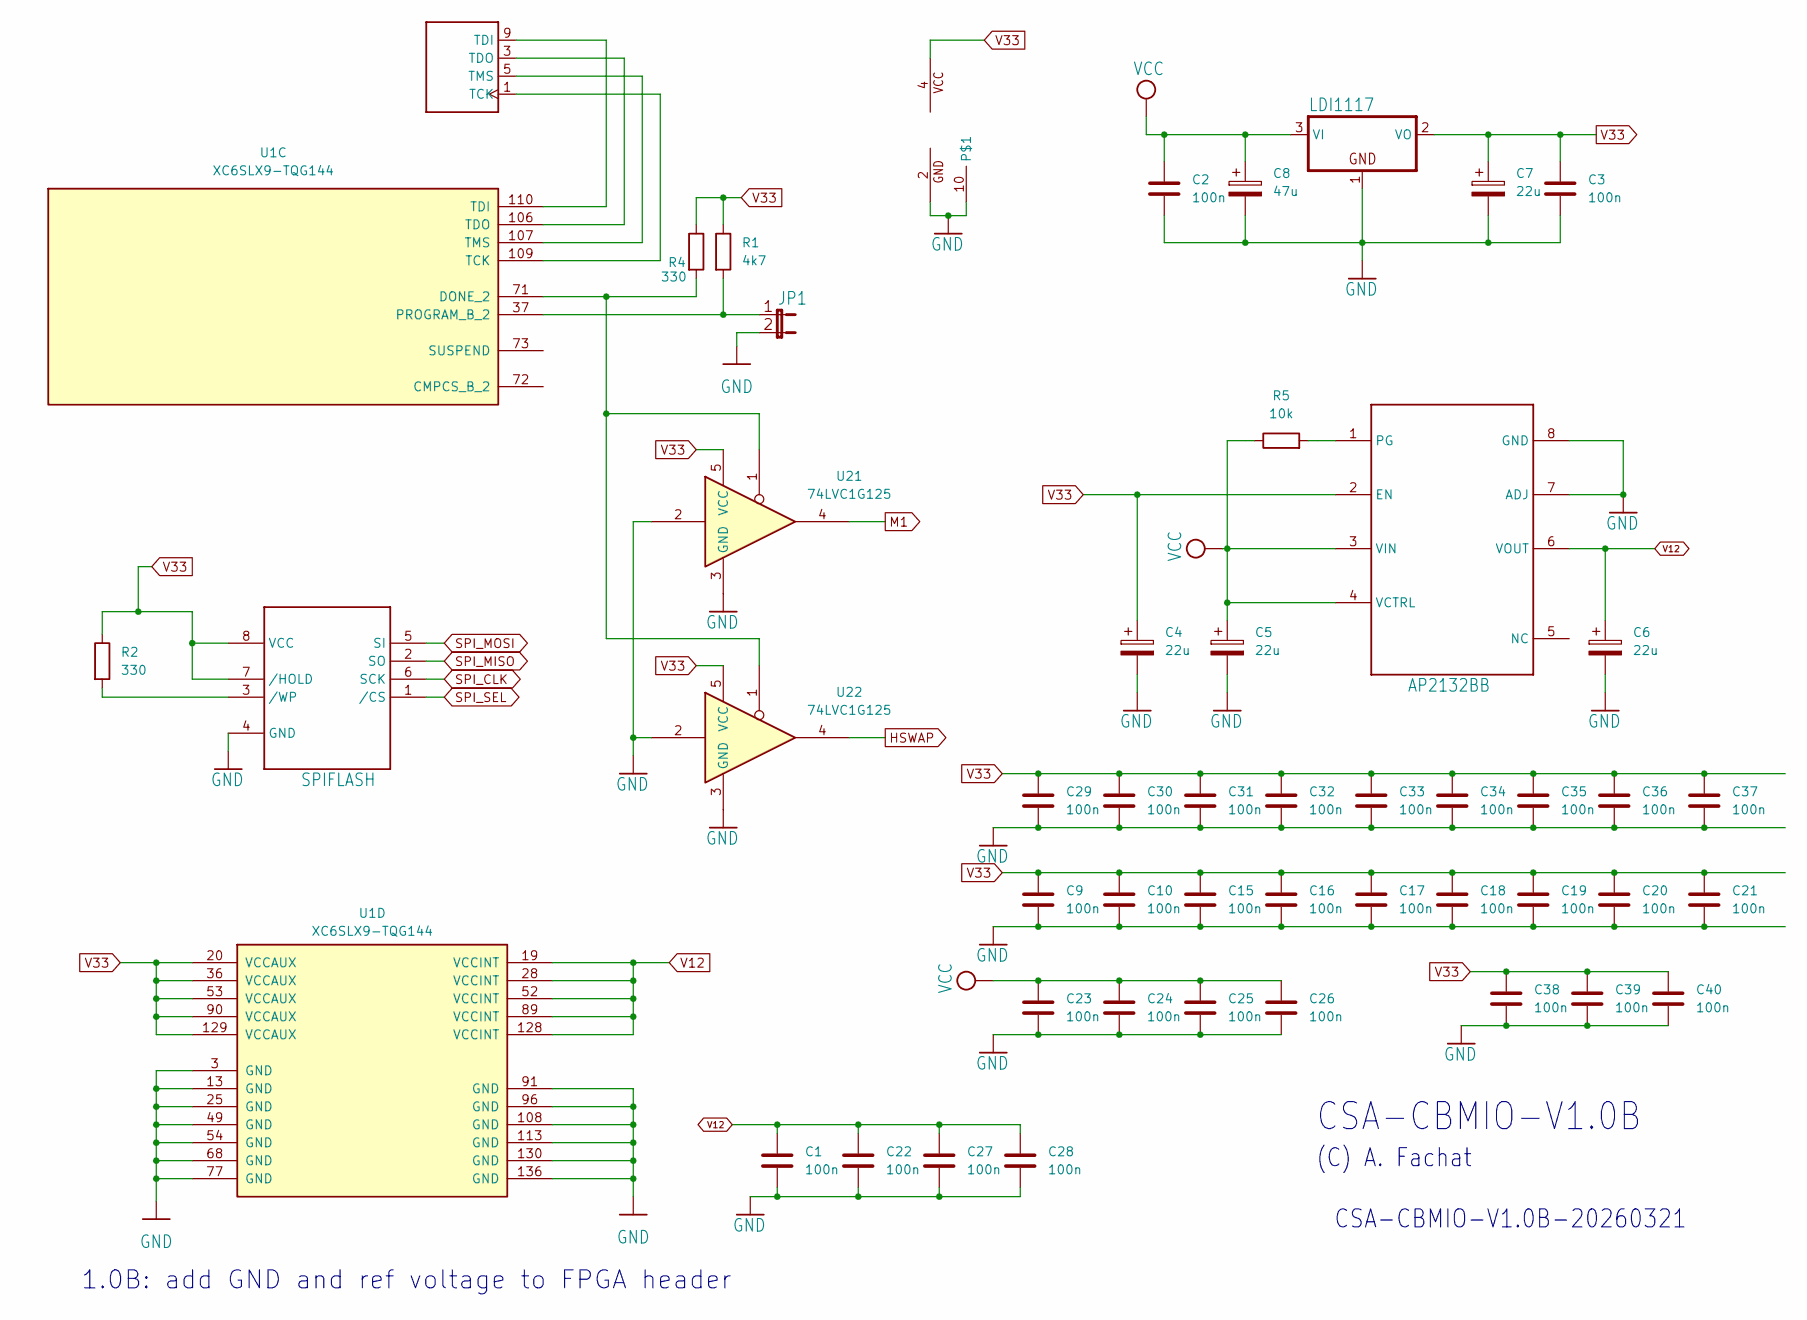
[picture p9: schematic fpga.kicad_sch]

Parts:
C1, C2, C3, C9, C10, C15, C16, C17, C18, C19, C20, C21, C22, C23, C24, C25, C26, C27, C28, C29, C30, C31, C32, C33, C34, C35, C36, C37, C38, C39, C40: 100n; C_0805_2012Metric
C4, C5, C6, C7: 22u; C_0805_2012Metric_Pad1.18x1.45mm_HandSolder
C8: 47u; C_0805_2012Metric_Pad1.18x1.45mm_HandSolder
JP1: JP1E; JP1
R1: 4k7; R_0603_1608Metric_Pad0.98x0.95mm_HandSolder
R2, R4: 330; R_0603_1608Metric_Pad0.98x0.95mm_HandSolder
R5: 10k; R_0603_1608Metric_Pad0.98x0.95mm_HandSolder
U1: XC6SLX9-TQG144
U21, U22: 74LVC1G125; SOT-353_SC-70-5
UX7: XILINXPROG; IDC-Header_2x05_P2.54mm_Vertical
UX16: AP2132BB; Diodes_PSOP-8
UX17: LDI1117; SOT-223
UX18: SPIFLASH; DIP-8_W7.62mm_Socket_LongPads

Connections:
CLKOUT: U22.4; also elsewhere on the board
CWR: U21.4; also elsewhere on the board
GND: C1.2, C2.2, C3.2, C4.2, C5.2, C6.2, C7.2, C8.2, C9.2, C10.2, C15.2, C16.2, C17.2, C18.2, C19.2, C20.2, C21.2, C22.2, C23.2, C24.2, C25.2, C26.2, C27.2, C28.2, C29.2, C30.2, C31.2, C32.2, C33.2, C34.2, C35.2, C36.2, C37.2, C38.2, C39.2, C40.2, JP1.2, U1.3 (GND), U1.13 (GND), U1.25 (GND), U1.49 (GND), U1.54 (GND), U1.68 (GND), U1.77 (GND), U1.91 (GND), U1.96 (GND), U1.108 (GND), U1.113 (GND), U1.130 (GND), U1.136 (GND), U21.2, U21.3 (GND), U22.2, U22.3 (GND), UX7.2 (GND), UX7.10, UX16.7 (ADJ), UX16.8 (GND), UX17.1 (GND), UX18.4 (GND); also elsewhere on the board
unnamed: R4.2, U1.71 (DONE_2), U21.1, U22.1
unnamed: JP1.1, R1.2, U1.37 (PROGRAM_B_2)
unnamed: U1.109 (TCK), UX7.1 (TCK)
unnamed: U1.110 (TDI), UX7.9 (TDI)
unnamed: U1.106 (TDO), UX7.3 (TDO)
unnamed: U1.107 (TMS), UX7.5 (TMS)
unnamed: R5.2, UX16.1 (PG)
unnamed: R2.2, UX18.3 (/WP)
SPI_CLK: UX18.6 (SCK); also elsewhere on the board
SPI_MISO: UX18.2 (SO); also elsewhere on the board
SPI_MOSI: UX18.5 (SI); also elsewhere on the board
SPI_SEL: UX18.1 (/CS); also elsewhere on the board
V12: C1.1, C6.1, C22.1, C27.1, C28.1, U1.19 (VCCINT), U1.28 (VCCINT), U1.52 (VCCINT), U1.89 (VCCINT), U1.128 (VCCINT), UX16.6 (VOUT)
V33: C3.1, C4.1, C7.1, C9.1, C10.1, C15.1, C16.1, C17.1, C18.1, C19.1, C20.1, C21.1, C29.1, C30.1, C31.1, C32.1, C33.1, C34.1, C35.1, C36.1, C37.1, C38.1, C39.1, C40.1, R1.1, R2.1, R4.1, U1.20 (VCCAUX), U1.36 (VCCAUX), U1.53 (VCCAUX), U1.90 (VCCAUX), U1.129 (VCCAUX), U21.5 (VCC), U22.5 (VCC), UX7.4 (VCC), UX16.2 (EN), UX17.2 (VO), UX18.7 (/HOLD), UX18.8 (VCC); also elsewhere on the board
VCC: C2.1, C5.1, C8.1, C23.1, C24.1, C25.1, C26.1, R5.1, UX16.3 (VIN), UX16.4 (VCTRL), UX17.3 (VI); also elsewhere on the board

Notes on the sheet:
CSA-CBMIO-V1.0B
1.0B: add GND and ref voltage to FPGA header
(C) A. Fachat
CSA-CBMIO-V1.0B-20260321

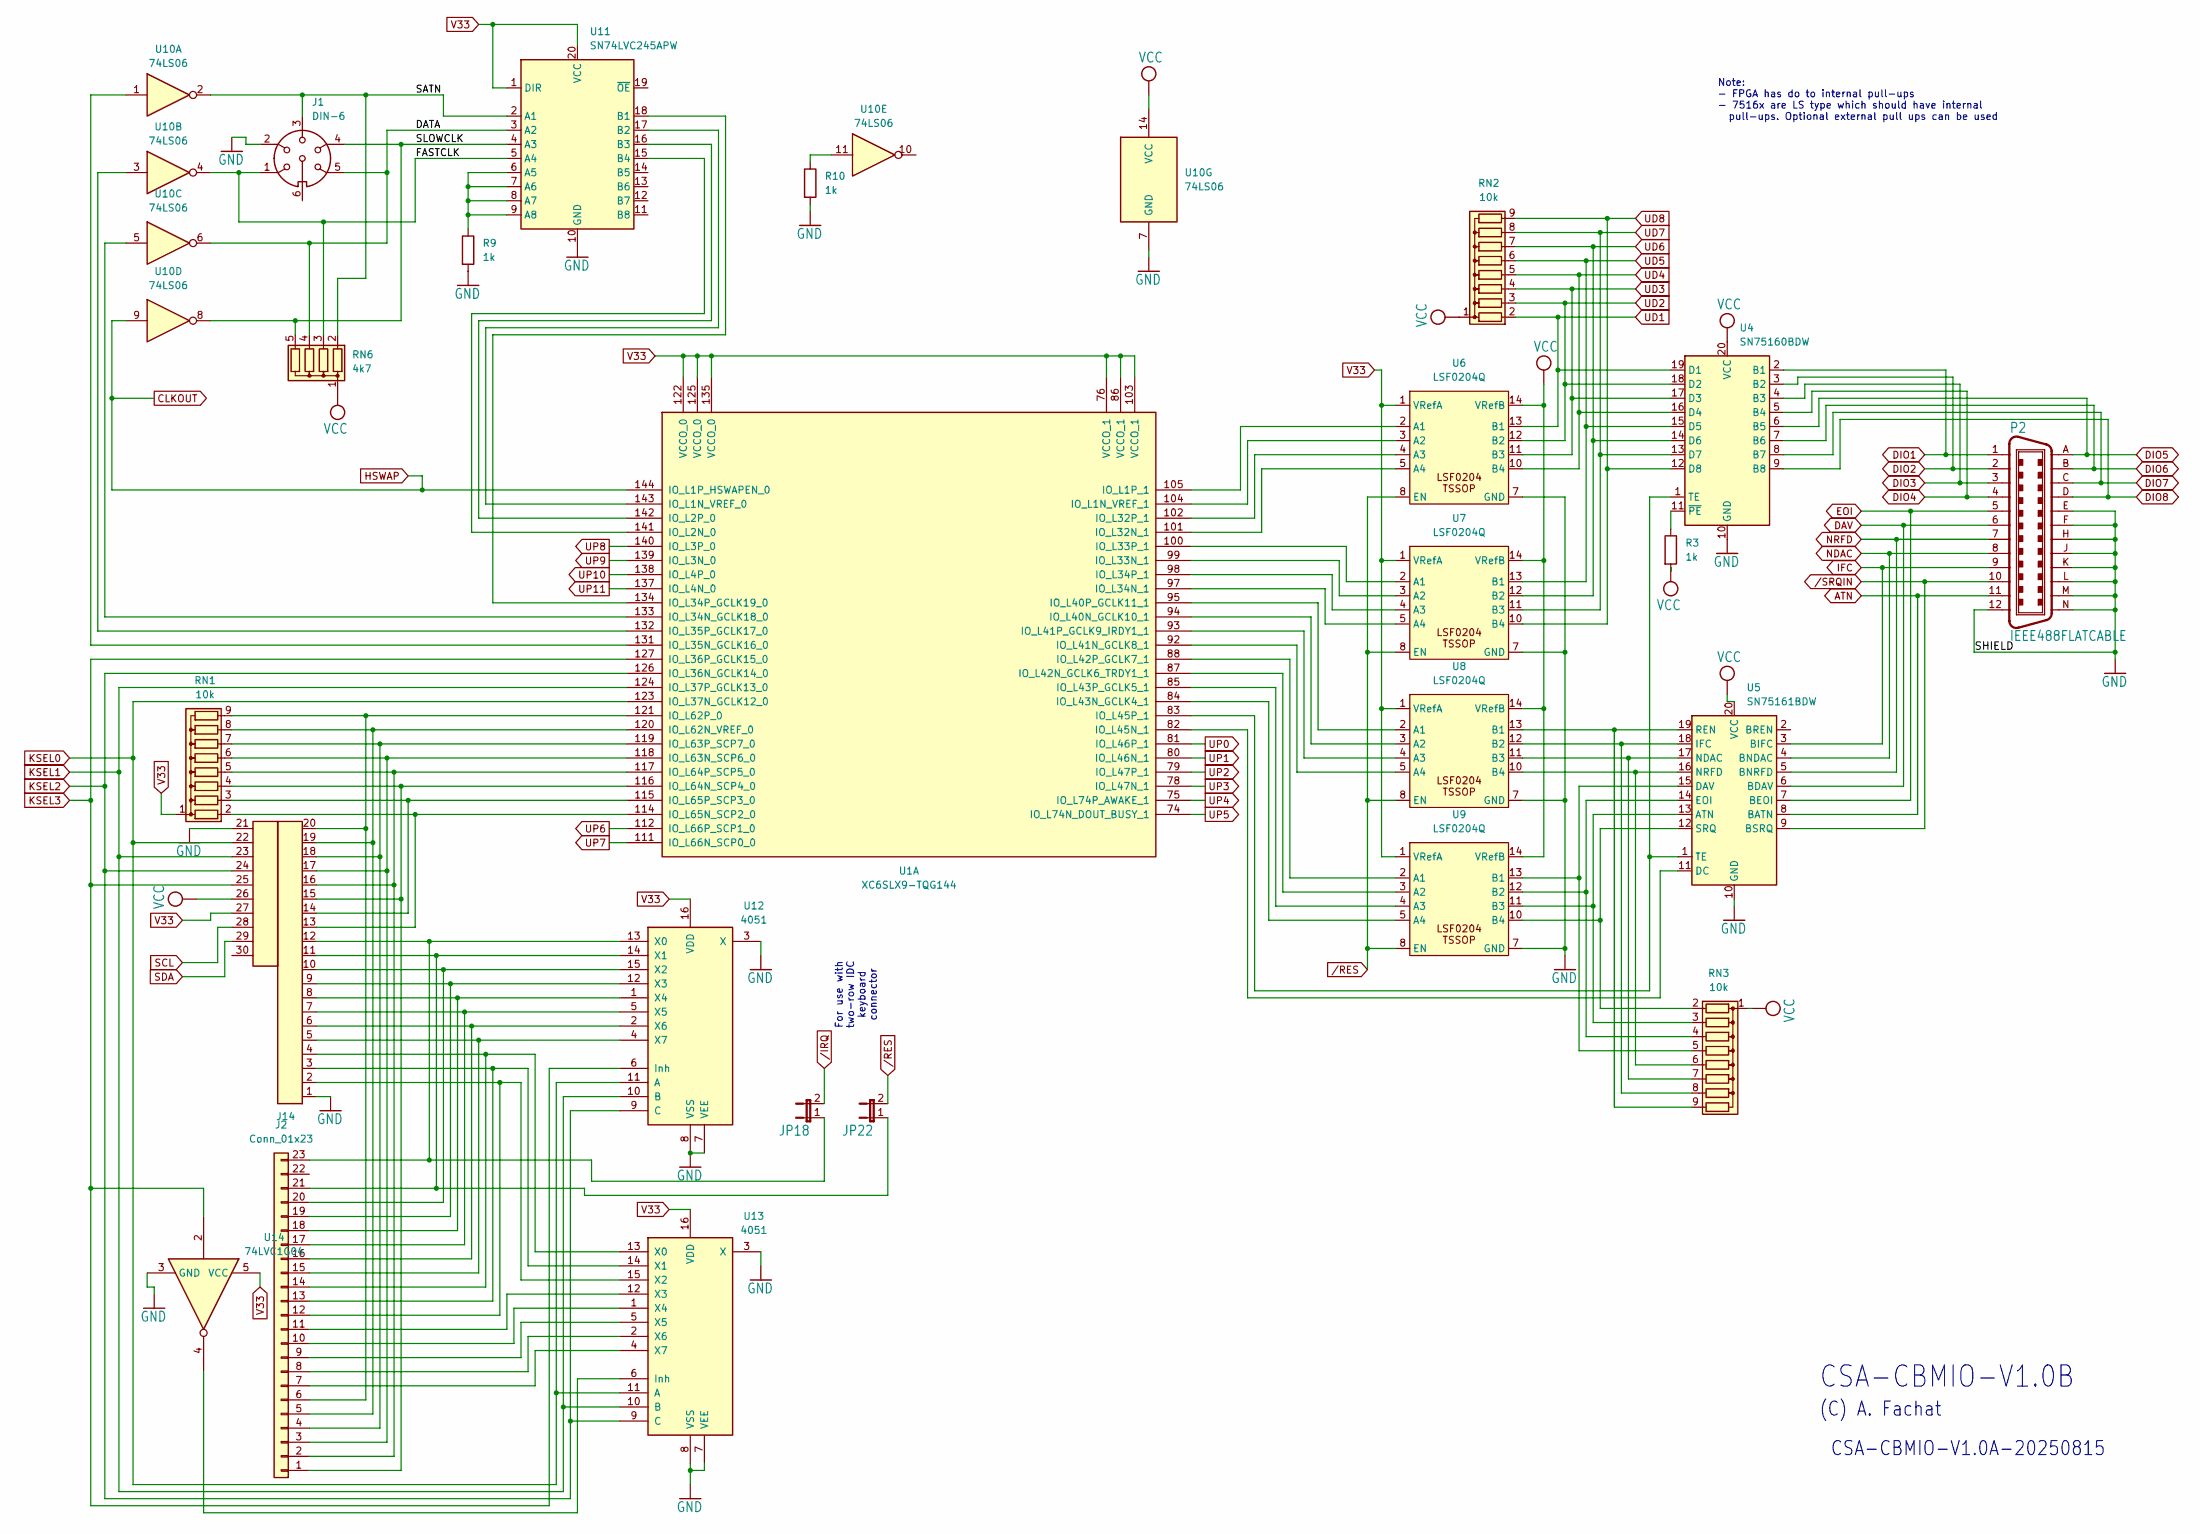
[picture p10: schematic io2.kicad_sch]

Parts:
J1: DIN-6; DIN6PIEC
J2: Conn_01x23; PinSocket_1x23_P2.54mm_Vertical
J14: Extended_PET_keyboard_connector; PET_Extended_Keyboard_Connector
JP18, JP22: JP1E; PinHeader_1x02_P2.54mm_Vertical
P2: IEEE488FLATCABLE; FLAT24_IDC
R3, R9, R10: 1k; R_0603_1608Metric_Pad0.98x0.95mm_HandSolder
RN1, RN2, RN3: 10k; R_Array_SIP9
RN6: 4k7; R_Array_SIP5
U1: XC6SLX9-TQG144; TQFP-144_20x20mm_P0.5mm
U4: SN75160BDW; SOIC-20W_7.5x12.8mm_P1.27mm
U5: SN75161BDW; SOIC-20W_7.5x12.8mm_P1.27mm
U6, U7, U8, U9: LSF0204Q; TSSOP-14_4.4x5mm_P0.65mm
U10: 74LS06; SO-14_3.9x8.65mm_P1.27mm
U11: SN74LVC245APW; TSSOP-20_4.4x6.5mm_P0.65mm
U12, U13: 4051; SOP-16_3.9x9.9mm_P1.27mm
U14: 74LVC1G04; SOT-23-5

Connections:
/IO2/DATA: J1.5, RN6.4 (R3), U10.6, U11.3 (A2)
/IO2/FASTCLK: J1.1, RN6.3 (R2), U10.4, U11.5 (A4)
/IO2/SATN: J1.3, RN6.2 (R1), U10.2, U11.2 (A1)
/IO2/SLOWCLK: J1.4, RN6.5 (R4), U10.8, U11.4 (A3)
ATN: P2.11, U5.8 (BATN)
CLKOUT: U1.144 (IO_L1P_HSWAPEN_0), U10.9; also elsewhere on the board
DAV: P2.6, U5.6 (BDAV)
DIO1: P2.1, U4.2 (B1)
DIO2: P2.2, U4.3 (B2)
DIO3: P2.3, U4.4 (B3)
DIO4: P2.4, U4.5 (B4)
DIO5: P2.A (13), U4.6 (B5)
DIO6: P2.B (14), U4.7 (B6)
DIO7: P2.C (15), U4.8 (B7)
DIO8: P2.D (16), U4.9 (B8)
EOI: P2.5, U5.7 (BEOI); also elsewhere on the board
GND: J1.2, J14.1, J14.21 (GND), P2.12, P2.E (17), P2.F (18), P2.H (19), P2.J (20), P2.K (21), P2.L (22), P2.M (23), P2.N (24), R9.2, R10.2, U4.10 (GND), U5.10 (GND), U6.7 (GND), U7.7 (GND), U8.7 (GND), U9.7 (GND), U10.7 (GND), U11.10 (GND), U12.3 (X), U12.7 (VEE), U12.8 (VSS), U13.3 (X), U13.7 (VEE), U13.8 (VSS), U14.3 (GND); also elsewhere on the board
IFC: P2.9, U5.3 (BIFC)
KSEL0: J14.22 (S0), U1.123 (IO_L37N_GCLK12_0), U12.11 (A), U13.11 (A)
KSEL1: J14.23 (S1), U1.124 (IO_L37P_GCLK13_0), U12.10 (B), U13.10 (B)
KSEL2: J14.24 (S2), U1.126 (IO_L36N_GCLK14_0), U12.9 (C), U13.9 (C)
KSEL3: J14.25 (S3), U1.127 (IO_L36P_GCLK15_0), U12.6 (Inh), U14.2
NDAC: P2.8, U5.4 (BNDAC)
NRFD: P2.7, U5.5 (BNRFD)
unnamed: J2.1, J14.15, RN1.4 (R3), U1.116 (IO_L64N_SCP4_0)
unnamed: J2.2, J14.16, RN1.5 (R4), U1.117 (IO_L64P_SCP5_0)
unnamed: J2.3, J14.17, RN1.6 (R5), U1.118 (IO_L63N_SCP6_0)
unnamed: J2.4, J14.18, RN1.7 (R6), U1.119 (IO_L63P_SCP7_0)
unnamed: J2.5, J14.19, RN1.8 (R7), U1.120 (IO_L62N_VREF_0)
unnamed: J2.6, J14.20, RN1.9 (R8), U1.121 (IO_L62P_0)
unnamed: J2.7, U13.4 (X7)
unnamed: J2.8, U13.2 (X6)
unnamed: J2.9, U13.5 (X5)
unnamed: J2.10, U13.1 (X4)
unnamed: J2.11, U13.12 (X3)
unnamed: J2.12, J14.2, U13.15 (X2)
unnamed: J2.13, J14.3, U13.14 (X1)
unnamed: J2.14, J14.4, U13.13 (X0)
unnamed: J2.15, J14.5, U12.4 (X7)
unnamed: J2.16, J14.6, U12.2 (X6)
unnamed: J2.17, J14.7, U12.5 (X5)
unnamed: J2.18, J14.8, U12.1 (X4)
unnamed: J2.19, J14.9, U12.12 (X3)
unnamed: J2.20, J14.10, U12.15 (X2)
unnamed: J2.21, J14.11, JP22.1, U12.14 (X1)
unnamed: J2.23, J14.12, JP18.1, U12.13 (X0)
unnamed: R10.1, U10.11
unnamed: J14.13, RN1.2 (R1), U1.114 (IO_L65N_SCP2_0)
unnamed: J14.14, RN1.3 (R2), U1.115 (IO_L65P_SCP3_0)
unnamed: RN3.2 (R1), U5.12 (SRQ), U9.10 (B4)
unnamed: RN3.3 (R2), U5.13 (ATN), U9.11 (B3)
unnamed: RN3.4 (R3), U5.14 (EOI), U9.12 (B2)
unnamed: RN3.5 (R4), U5.15 (DAV), U9.13 (B1)
unnamed: RN3.6 (R5), U5.16 (NRFD), U8.10 (B4)
unnamed: RN3.7 (R6), U5.17 (NDAC), U8.11 (B3)
unnamed: RN3.8 (R7), U5.18 (IFC), U8.12 (B2)
unnamed: RN3.9 (R8), U5.19 (REN), U8.13 (B1)
unnamed: U1.104 (IO_L1N_VREF_1), U6.3 (A2)
unnamed: U1.105 (IO_L1P_1), U6.2 (A1)
unnamed: U1.101 (IO_L32N_1), U6.5 (A4)
unnamed: U1.102 (IO_L32P_1), U6.4 (A3)
unnamed: U1.99 (IO_L33N_1), U7.3 (A2)
unnamed: U1.100 (IO_L33P_1), U7.2 (A1)
unnamed: U1.97 (IO_L34N_1), U7.5 (A4)
unnamed: U1.133 (IO_L34N_GCLK18_0), U10.5
unnamed: U1.98 (IO_L34P_1), U7.4 (A3)
unnamed: U1.131 (IO_L35N_GCLK16_0), U10.1
unnamed: U1.132 (IO_L35P_GCLK17_0), U10.3
unnamed: U1.94 (IO_L40N_GCLK10_1), U8.3 (A2)
unnamed: U1.95 (IO_L40P_GCLK11_1), U8.2 (A1)
unnamed: U1.92 (IO_L41N_GCLK8_1), U8.5 (A4)
unnamed: U1.93 (IO_L41P_GCLK9_IRDY1_1), U8.4 (A3)
unnamed: U1.87 (IO_L42N_GCLK6_TRDY1_1), U9.3 (A2)
unnamed: U1.88 (IO_L42P_GCLK7_1), U9.2 (A1)
unnamed: U1.84 (IO_L43N_GCLK4_1), U9.5 (A4)
unnamed: U1.85 (IO_L43P_GCLK5_1), U9.4 (A3)
unnamed: U1.82 (IO_L45N_1), U5.11 (DC)
unnamed: U1.83 (IO_L45P_1), U4.1 (TE), U5.1 (TE)
unnamed: R3.1, U4.11 (~PE)
unnamed: R9.1, U11.6 (A5), U11.7 (A6), U11.8 (A7), U11.9 (A8)
unnamed: U1.134 (IO_L34P_GCLK19_0), U11.18 (B1)
unnamed: U1.143 (IO_L1N_VREF_0), U11.17 (B2)
unnamed: U1.142 (IO_L2P_0), U11.16 (B3)
unnamed: U1.141 (IO_L2N_0), U11.15 (B4)
unnamed: U13.6 (Inh), U14.4
SCL: J14.28 (SCL)
SDA: J14.29 (SCA)
UD1: RN2.2 (R1), U4.19 (D1), U6.13 (B1); also elsewhere on the board
UD2: RN2.3 (R2), U4.18 (D2), U6.12 (B2); also elsewhere on the board
UD3: RN2.4 (R3), U4.17 (D3), U6.11 (B3); also elsewhere on the board
UD4: RN2.5 (R4), U4.16 (D4), U6.10 (B4); also elsewhere on the board
UD5: RN2.6 (R5), U4.15 (D5), U7.13 (B1); also elsewhere on the board
UD6: RN2.7 (R6), U4.14 (D6), U7.12 (B2); also elsewhere on the board
UD7: RN2.8 (R7), U4.13 (D7), U7.11 (B3); also elsewhere on the board
UD8: RN2.9 (R8), U4.12 (D8), U7.10 (B4); also elsewhere on the board
UP0: U1.81 (IO_L46P_1); also elsewhere on the board
UP1: U1.80 (IO_L46N_1); also elsewhere on the board
UP2: U1.79 (IO_L47P_1); also elsewhere on the board
UP3: U1.78 (IO_L47N_1); also elsewhere on the board
UP4: U1.75 (IO_L74P_AWAKE_1); also elsewhere on the board
UP5: U1.74 (IO_L74N_DOUT_BUSY_1); also elsewhere on the board
UP6: U1.112 (IO_L66P_SCP1_0); also elsewhere on the board
UP7: U1.111 (IO_L66N_SCP0_0); also elsewhere on the board
UP8: U1.140 (IO_L3P_0); also elsewhere on the board
UP9: U1.139 (IO_L3N_0); also elsewhere on the board
UP10: U1.138 (IO_L4P_0); also elsewhere on the board
UP11: U1.137 (IO_L4N_0); also elsewhere on the board
V33: J14.27 (VCC33), RN1.1 (common), U1.76 (VCCO_1), U1.86 (VCCO_1), U1.103 (VCCO_1), U1.122 (VCCO_0), U1.125 (VCCO_0), U1.135 (VCCO_0), U6.1 (VRefA), U7.1 (VRefA), U8.1 (VRefA), U9.1 (VRefA), U11.1 (DIR), U11.20 (VCC), U12.16 (VDD), U13.16 (VDD), U14.5 (VCC); also elsewhere on the board
VCC: J14.26 (VCC5), R3.2, RN2.1 (common), RN3.1 (common), RN6.1 (common), U4.20 (VCC), U5.20 (VCC), U6.14 (VRefB), U7.14 (VRefB), U8.14 (VRefB), U9.14 (VRefB), U10.14 (VCC); also elsewhere on the board
/IRQ: JP18.2; also elsewhere on the board
/RES: JP22.2, U6.8 (EN), U7.8 (EN), U8.8 (EN), U9.8 (EN); also elsewhere on the board

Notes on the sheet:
For use with two-row IDC keyboard connector
CSA-CBMIO-V1.0B
Note: - FPGA has do to internal pull-ups - 7516x are LS type which should have internal pull-ups. Optional external pull ups can be used
CSA-CBMIO-V1.0A-20250815
(C) A. Fachat

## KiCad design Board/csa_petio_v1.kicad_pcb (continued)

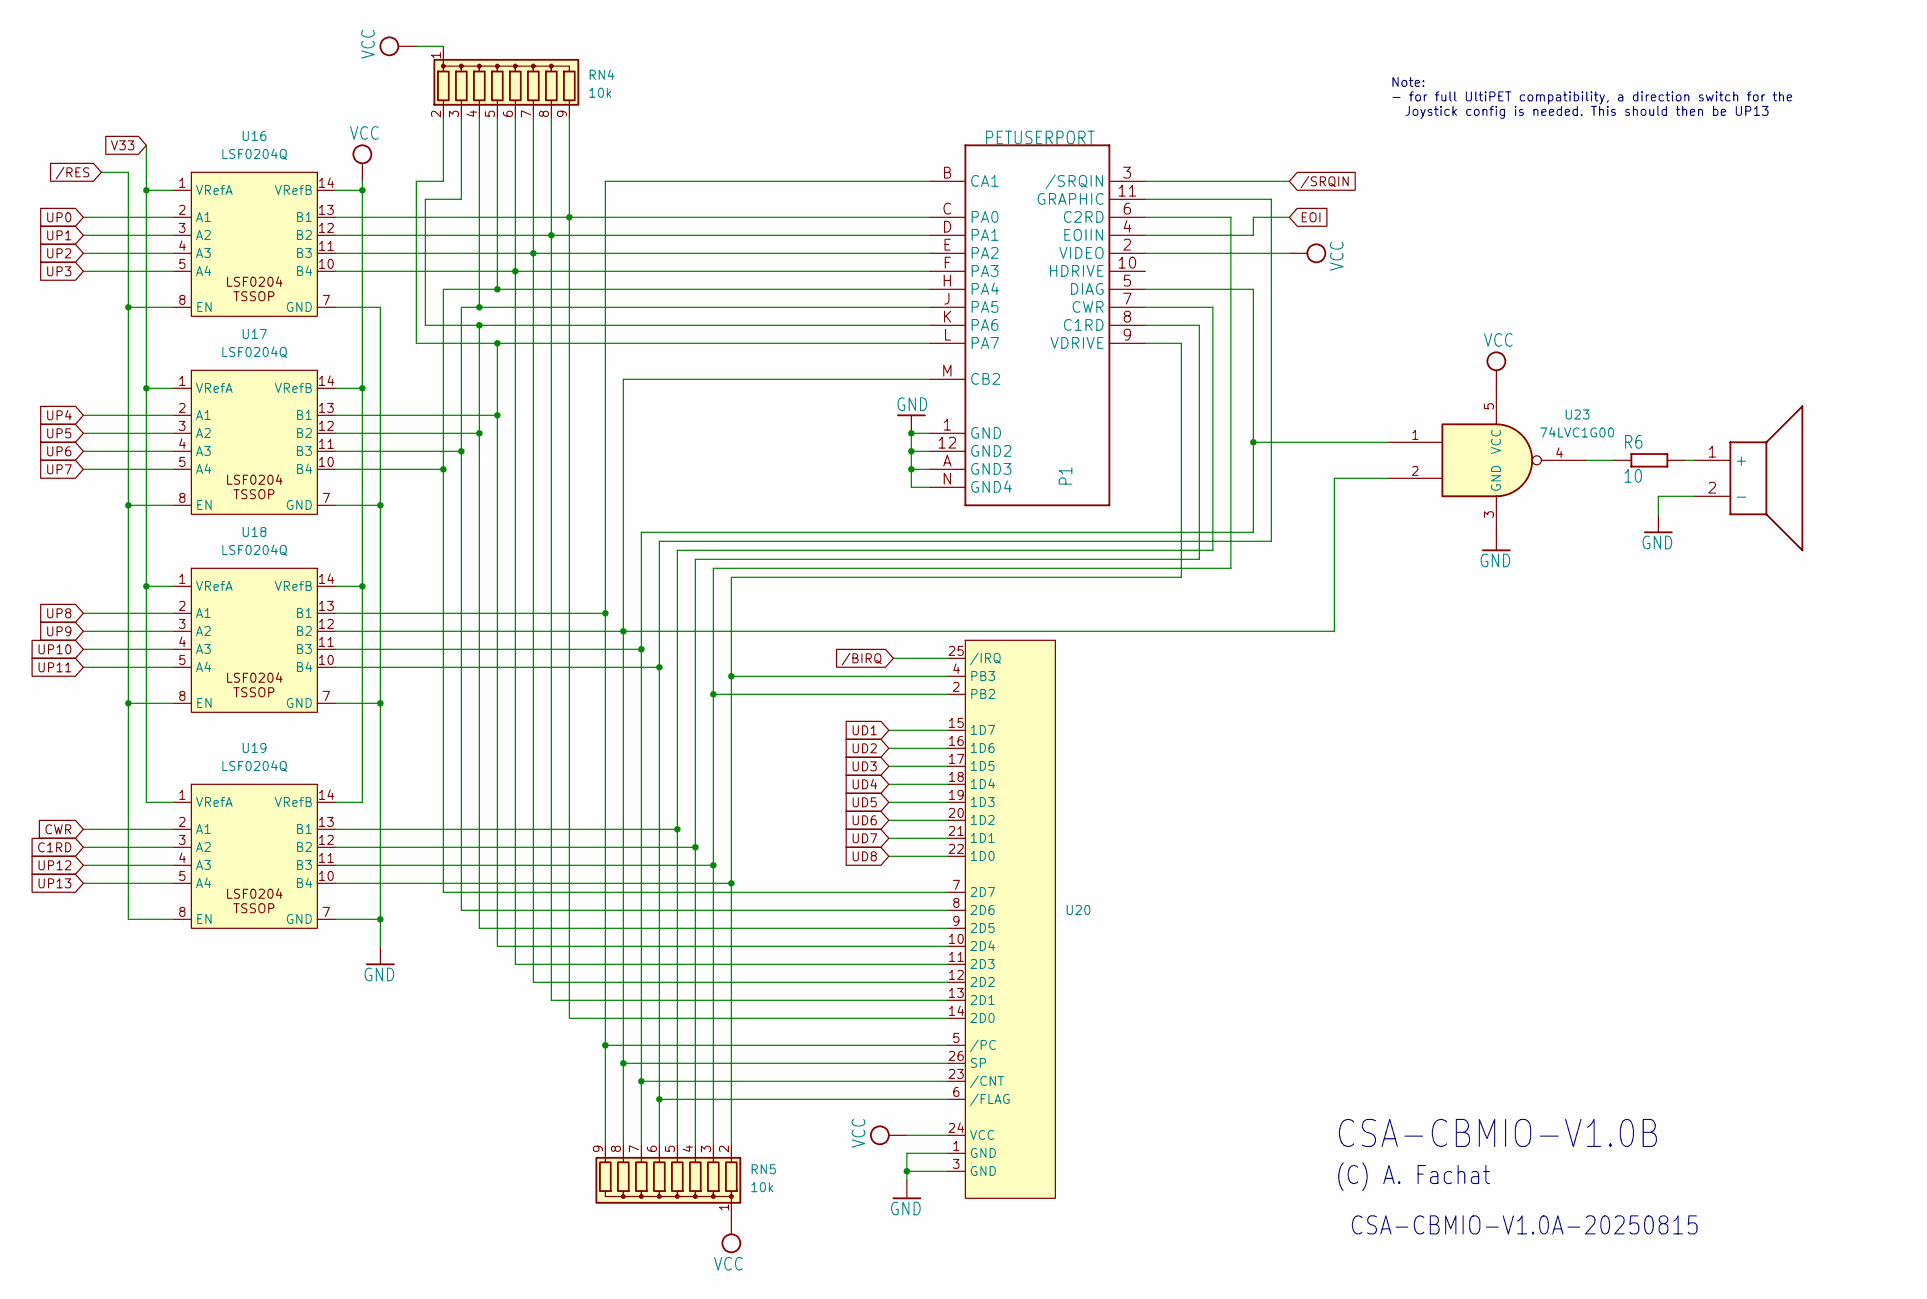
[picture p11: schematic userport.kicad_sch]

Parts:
BEEP1: PIEZOBEEPERPIEZO; PIEZOBEEPER
P1: PETUSERPORT; FLAT24_IDC
R6: 10; 0207_10
RN4, RN5: 10k; R_Array_SIP9
U16, U17, U18, U19: LSF0204Q; TSSOP-14_4.4x5mm_P0.65mm
U20: IDC-Header_2x13_P2.54mm_Vertical
U23: 74LVC1G00; SOT-353_SC-70-5_Handsoldering

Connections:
C1RD: U19.3 (A2); also elsewhere on the board
CWR: U19.2 (A1); also elsewhere on the board
EOI: P1.4 (EOIIN); also elsewhere on the board
GND: BEEP1.2 (-), P1.1 (GND), P1.12 (GND2), P1.A (GND3), P1.N (GND4), U16.7 (GND), U17.7 (GND), U18.7 (GND), U19.7 (GND), U20.1 (GND), U20.3 (GND), U23.3 (GND); also elsewhere on the board
unnamed: BEEP1.1 (+), R6.2
unnamed: P1.8 (C1RD), RN5.4 (R3), U19.12 (B2)
unnamed: P1.6 (C2RD), RN5.3 (R2), U19.11 (B3), U20.2 (PB2)
unnamed: P1.B (CA1), RN5.9 (R8), U18.13 (B1), U20.5 (/PC)
unnamed: P1.M (CB2), RN5.8 (R7), U18.12 (B2), U20.26 (SP), U23.2
unnamed: P1.7 (CWR), RN5.5 (R4), U19.13 (B1)
unnamed: P1.5 (DIAG), RN5.7 (R6), U18.11 (B3), U20.23 (/CNT), U23.1
unnamed: P1.11 (GRAPHIC), RN5.6 (R5), U18.10 (B4), U20.6 (/FLAG)
unnamed: P1.C (PA0), RN4.9 (R8), U16.13 (B1), U20.14 (2D0)
unnamed: P1.D (PA1), RN4.8 (R7), U16.12 (B2), U20.13 (2D1)
unnamed: P1.E (PA2), RN4.7 (R6), U16.11 (B3), U20.12 (2D2)
unnamed: P1.F (PA3), RN4.6 (R5), U16.10 (B4), U20.11 (2D3)
unnamed: P1.H (PA4), RN4.5 (R4), U17.10 (B4), U20.7 (2D7)
unnamed: P1.J (PA5), RN4.4 (R3), U17.11 (B3), U20.8 (2D6)
unnamed: P1.K (PA6), RN4.3 (R2), U17.12 (B2), U20.9 (2D5)
unnamed: P1.L (PA7), RN4.2 (R1), U17.13 (B1), U20.10 (2D4)
unnamed: P1.9 (VDRIVE), RN5.2 (R1), U19.10 (B4), U20.4 (PB3)
unnamed: R6.1, U23.4
UD1: U20.15 (1D7); also elsewhere on the board
UD2: U20.16 (1D6); also elsewhere on the board
UD3: U20.17 (1D5); also elsewhere on the board
UD4: U20.18 (1D4); also elsewhere on the board
UD5: U20.19 (1D3); also elsewhere on the board
UD6: U20.20 (1D2); also elsewhere on the board
UD7: U20.21 (1D1); also elsewhere on the board
UD8: U20.22 (1D0); also elsewhere on the board
UP0: U16.2 (A1); also elsewhere on the board
UP1: U16.3 (A2); also elsewhere on the board
UP2: U16.4 (A3); also elsewhere on the board
UP3: U16.5 (A4); also elsewhere on the board
UP4: U17.2 (A1); also elsewhere on the board
UP5: U17.3 (A2); also elsewhere on the board
UP6: U17.4 (A3); also elsewhere on the board
UP7: U17.5 (A4); also elsewhere on the board
UP8: U18.2 (A1); also elsewhere on the board
UP9: U18.3 (A2); also elsewhere on the board
UP10: U18.4 (A3); also elsewhere on the board
UP11: U18.5 (A4); also elsewhere on the board
UP12: U19.4 (A3); also elsewhere on the board
UP13: U19.5 (A4); also elsewhere on the board
V33: U16.1 (VRefA), U17.1 (VRefA), U18.1 (VRefA), U19.1 (VRefA); also elsewhere on the board
VCC: P1.2 (VIDEO), RN4.1 (common), RN5.1 (common), U16.14 (VRefB), U17.14 (VRefB), U18.14 (VRefB), U19.14 (VRefB), U20.24 (VCC), U23.5 (VCC); also elsewhere on the board
/BIRQ: U20.25 (/IRQ); also elsewhere on the board
/RES: U16.8 (EN), U17.8 (EN), U18.8 (EN), U19.8 (EN); also elsewhere on the board

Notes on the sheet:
Note: - for full UltiPET compatibility, a direction switch for the Joystick config is needed. This should then be UP13
CSA-CBMIO-V1.0B
(C) A. Fachat
CSA-CBMIO-V1.0A-20250815

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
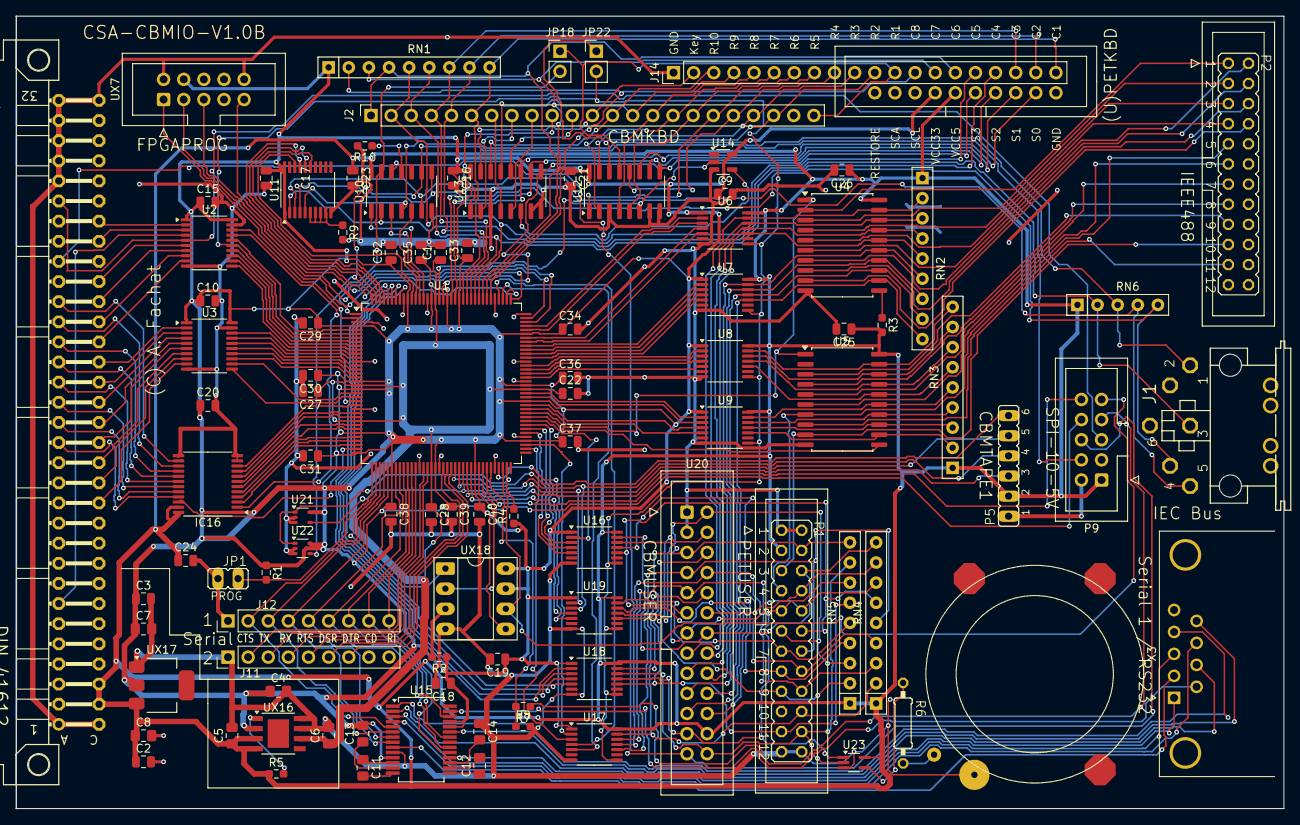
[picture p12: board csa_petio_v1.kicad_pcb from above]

Board: 2 copper layers, 160.0 x 100.0 mm, 99 parts (0 on the bottom side), 227 nets.

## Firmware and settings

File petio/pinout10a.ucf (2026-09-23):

# bus

# phi2 is on a GCLK pin!
# required due to UART's use with too many non-clock resources
net phi2 			loc=p23 | iostandard=lvttl;
net phi2				bufg=clk | PERIOD=1000;
net phi2				clock_dedicated_route = false;

INST "phi2_bufg" LOC = BUFGMUX_X2Y10;
#INST "phi2_ibufg_bufg.o" LOC = BUFGMUX_X2Y11;

net rwb				loc=p2 | iostandard=lvcmos33;
net niosel			loc=p5 | iostandard=lvcmos33;
net nres				loc=p6 | iostandard=lvcmos33;
net irq				loc=p1 | iostandard=lvcmos33;
net nbe				loc=p35 | iostandard=lvcmos33;

net a<0>				loc=p7 | iostandard=lvttl;
net a<1>				loc=p8 | iostandard=lvttl;
net a<2>				loc=p9 | iostandard=lvttl;
net a<3>				loc=p10 | iostandard=lvttl;
net a<4>				loc=p11 | iostandard=lvttl;
net a<5>				loc=p12 | iostandard=lvttl;
net a<6>				loc=p14 | iostandard=lvttl;
net a<7>				loc=p15 | iostandard=lvttl;
net a<8>				loc=p16 | iostandard=lvttl;
net a<9>				loc=p17 | iostandard=lvttl;
net a<10>			loc=p21 | iostandard=lvttl;
net a<11>			loc=p22 | iostandard=lvttl;

net d<0>				loc=p24 | iostandard=lvttl;
net d<1>				loc=p26 | iostandard=lvttl;
net d<2>				loc=p27 | iostandard=lvttl;
net d<3>				loc=p29 | iostandard=lvttl;
net d<4>				loc=p30 | iostandard=lvttl;
net d<5>				loc=p32 | iostandard=lvttl;
net d<6>				loc=p33 | iostandard=lvttl;
net d<7>				loc=p34 | iostandard=lvttl;

# serial (rs232)

net lcts				loc=p39 | iostandard=lvttl;
net lrts				loc=p43 | iostandard=lvttl;
net ltx				loc=p40 | iostandard=lvttl;
net lrx				loc=p41 | iostandard=lvttl;
net ldtr				loc=p45 | iostandard=lvttl;
net ldsr				loc=p44 | iostandard=lvttl;
net lri				loc=p47 | iostandard=lvttl;
net ldcd				loc=p46 | iostandard=lvttl;

net rcts				loc=p48 | iostandard=lvttl | pullup; # currently misused as config input
net rrts				loc=p55 | iostandard=lvttl;
net rtx				loc=p50 | iostandard=lvttl;
net rrx				loc=p51 | iostandard=lvttl | pullup;
net rdtr				loc=p57 | iostandard=lvttl;
net rdsr				loc=p56 | iostandard=lvttl;

# cassette

net c1sw				loc=p58	| iostandard=lvttl;
net cwr				loc=p60	| iostandard=lvttl;
net c1rd				loc=p59	| iostandard=lvttl;
net c1mtr			loc=p61	| iostandard=lvttl;

# SPI

net spiiosel		loc=p66	| iostandard=lvttl;
net spiclk			loc=p70	| iostandard=lvttl;
net spimiso			loc=p67	| iostandard=lvttl;
net spimosi			loc=p64	| iostandard=lvttl;

# serial IEC

net datain			loc=p143		| iostandard=lvttl;
net clkin			loc=p142		| iostandard=lvttl;
net satnin			loc=p134		| iostandard=lvttl;
net srqin			loc=p141		| iostandard=lvttl;

net dataout			loc=p133		| iostandard=lvttl;
net clkout			loc=p144		| iostandard=lvttl;
net satnout			loc=p131		| iostandard=lvttl;
net srqout			loc=p132		| iostandard=lvttl;

# keyboard

net ksel<0>			loc=p123		| iostandard=lvttl;
net ksel<1>			loc=p124		| iostandard=lvttl;
net ksel<2>			loc=p126		| iostandard=lvttl;
net ksel<3>			loc=p127		| iostandard=lvttl;

net kin<0>			loc=p121		| iostandard=lvttl;
net kin<1>			loc=p120		| iostandard=lvttl;
net kin<2>			loc=p119		| iostandard=lvttl;
net kin<3>			loc=p118		| iostandard=lvttl;
net kin<4>			loc=p117		| iostandard=lvttl;
net kin<5>			loc=p116		| iostandard=lvttl;
net kin<6>			loc=p115		| iostandard=lvttl;
net kin<7>			loc=p114		| iostandard=lvttl;

# IEEE488

net dio<0>			loc=p105		| iostandard=lvttl;
net dio<1>			loc=p104		| iostandard=lvttl;
net dio<2>			loc=p102		| iostandard=lvttl;
net dio<3>			loc=p101		| iostandard=lvttl;
net dio<4>			loc=p100		| iostandard=lvttl;
net dio<5>			loc=p99		| iostandard=lvttl;
net dio<6>			loc=p98		| iostandard=lvttl;
net dio<7>			loc=p97		| iostandard=lvttl;

net nrfd				loc=p92		| iostandard=lvttl;
net ndac				loc=p93		| iostandard=lvttl;
net dav				loc=p88		| iostandard=lvttl;
net eoi				loc=p87		| iostandard=lvttl;
net atn				loc=p85		| iostandard=lvttl;
net ifc				loc=p94		| iostandard=lvttl;
net ren				loc=p95		| iostandard=lvttl;
net psrq				loc=p84		| iostandard=lvttl;
net te				loc=p83		| iostandard=lvttl;
net dc				loc=p82		| iostandard=lvttl;


# userport

net up<0>			loc=p81	 | iostandard=lvttl;
net up<1>			loc=p80	 | iostandard=lvttl;
net up<2>			loc=p79	 | iostandard=lvttl;
net up<3>			loc=p78	 | iostandard=lvttl;
net up<4>			loc=p75	 | iostandard=lvttl;
net up<5>			loc=p74	 | iostandard=lvttl;
net up<6>			loc=p112	 | iostandard=lvttl;
net up<7>			loc=p111	 | iostandard=lvttl;
net up<8>			loc=p140	 | iostandard=lvttl;
net up<9>			loc=p139	 | iostandard=lvttl;
net up<10>			loc=p138	 | iostandard=lvttl;
net up<11>			loc=p137	 | iostandard=lvttl;
net up<12>			loc=p62	 | iostandard=lvttl;
net up<13>			loc=p69	 | iostandard=lvttl | pullup;

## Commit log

2025-08-14 adding keyboard, serial IEC
    [bus.kicad_sch, csa_petio_v1.kicad_pcb, csa_petio_v1.kicad_sch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]
2025-08-14 add serial, SPI-10-5V
    [bus.kicad_sch, csa_petio_v1.kicad_pcb, csa_petio_v1.kicad_sch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]
2025-08-14 schematics 1st full rev
    [bus.kicad_sch, csa_petio_v1.kicad_pcb, csa_petio_v1.kicad_sch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]
2025-08-14 add schematics
2025-08-24 full connect, starting on prod
    [bus.kicad_sch, csa_petio_v1.kicad_pcb, fpga.kicad_sch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]
2025-08-24 fix version on PCB
    [csa_petio_v1.kicad_pcb]
2025-08-24 prod files
    [BOM-csa_petio_v1.csv, csa_petio_v1.kicad_pcb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]
2025-08-24 prod files as submitted
    [BOM-csa_petio_v1.csv, csa_petio_v1.kicad_pcb]
2025-08-24 update PDF schematics
2026-03-21 1st working as 1.0B
    [bus.kicad_sch, csa_petio_v1.kicad_pcb, fpga.kicad_sch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]
2026-03-24 refactored via Timer A
2026-03-27 refactor via interrupt flags
2026-04-06 fix PIA CBx interrupt handling
2026-04-11 add initial UART
2026-08-02 Fix op token parsing and print invalid opc
2026-08-02 cleanup, some timer fix
2026-08-03 stabilize timer reads by not reloading if prev cycle was write
2026-08-04 rewrite via timer a with insights from 6522 dissection; fixes timer a tests
2026-08-04 cleanup timer a
2026-08-04 (still broken) rewrite of timer b
2026-08-09 Wire extracted CPU entity
2026-08-09 Add cross-wire connections between exposed pins in tb_shell_cpu
2026-08-15 work on timer a, sr
2026-09-12 Add qclk clock generator wiring
2026-09-12 Fix Shell sim UART binding
2026-09-12 Exercise qclk separately in UART sim
2026-09-12 fix bufg constraint, test qclk output on rrtx
    [pinout10a.ucf]
2026-09-19 Wire dedicated Timer 2 SR tick
2026-09-20 trying to fix timing
    [pinout10a.ucf]
2026-09-20 Wire phase enables into VIA
2026-09-20 Tighten Timer 2 phase alignment
2026-09-20 Split Timer 2 phase logic
2026-09-20 Make Timer 2 count enable combinational
2026-09-21 Extract VIA timer and serial modules
2026-09-21 Tighten VIA clocked process sensitivity
